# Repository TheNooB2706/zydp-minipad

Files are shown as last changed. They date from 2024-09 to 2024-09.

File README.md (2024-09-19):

# ZYDP miniPad - Hardware
This branch contains all the hardware designs (3D models, drawing and electrical schematic diagram) and images taken during the construction of the project. Unlike the software part, the organisation and documentation is much more messy.

## Files in the branch
1. `cad_model` folder contains all the 3D models in FreeCAD format and technical drawing in pdf of the project
1. `schematic` folder contains the electrical schematic in pdf and KiCAD files for the schematic and simulation
1. `images` folder contains images taken during the course of the project
1. `operation_guide` is a user manual for this project
1. `project_diaries` is a log of information throughout the project
1. `resources` is originally intended to be a place to keep all the links to the useful resources, but ended up being a log for setting up the bootloader

## Bill of materials

| **Item** | **Unit price** | **Qty** | **Cost** |
|---|---|---|---|
| **Electronics** | | | |
| Bluepill STM32F103C8T6 | 7.4 | 1 | 7.4 |
| Multiplexer 74HC4067 | 2.25 | 1 | 2.25 |
| 3.5mm Jack | 0.365 | 4 | 1.46 |
| Buttons | 0.0418 | 7 | 0.2926 |
| RGB LED common cathode | 0.13 | 1 | 0.13 |
| Ethernet cable for single core wire | 1.5 | 0.5 | 0.75 |
| NPN transistors 2SC1815 | 0.0496 | 2 | 0.0992 |
| Resistors (estimate price) | 0.016 | 21 | 0.336 |
| Prototyping board | 0.502 | 1 | 0.502 |
| Piezo elements | 0.3055 | 13 | 3.9715 |
| |
| **Mechanical** | | | |
| Sponge | 2.3 | 0.25 | 0.575 |
| EVA foam | 1.3 | 1 | 1.3 |
| Spray paint | 6.5 | 0.5 | 3.25 |
| Spray lacquer | 6.5 | 0.5 | 3.25 |
| Rubber feet | 0.104 | 6 | 0.624 |
| Mounting board | 3.5 | 1 | 3.5 |
| | | | |
| | |Total (RM)| 29.6903  |

## Image gallery

### Finished project
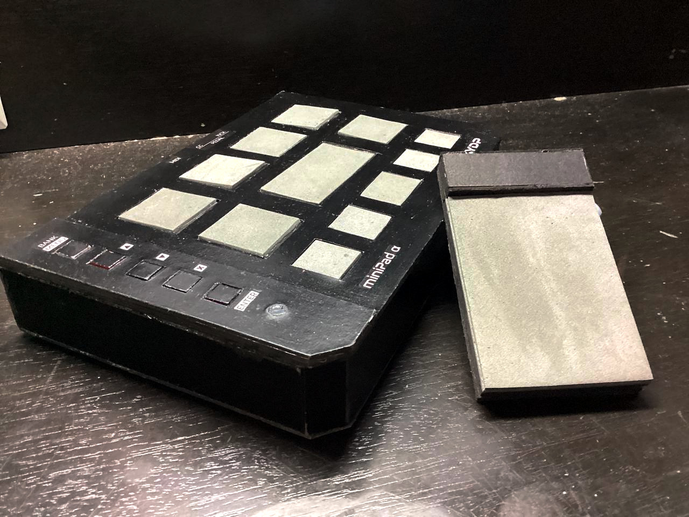
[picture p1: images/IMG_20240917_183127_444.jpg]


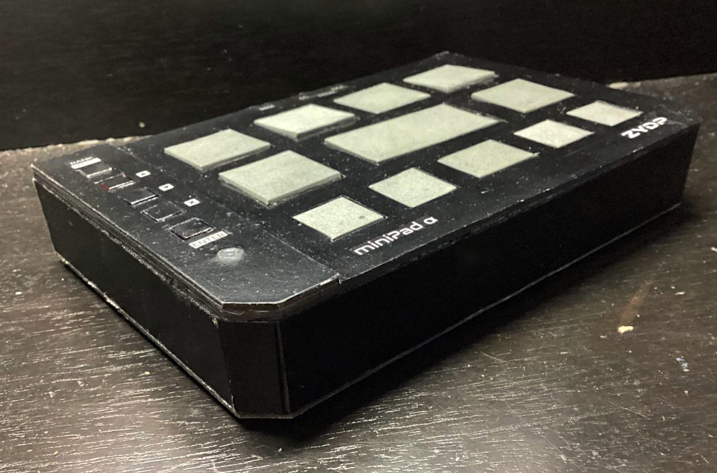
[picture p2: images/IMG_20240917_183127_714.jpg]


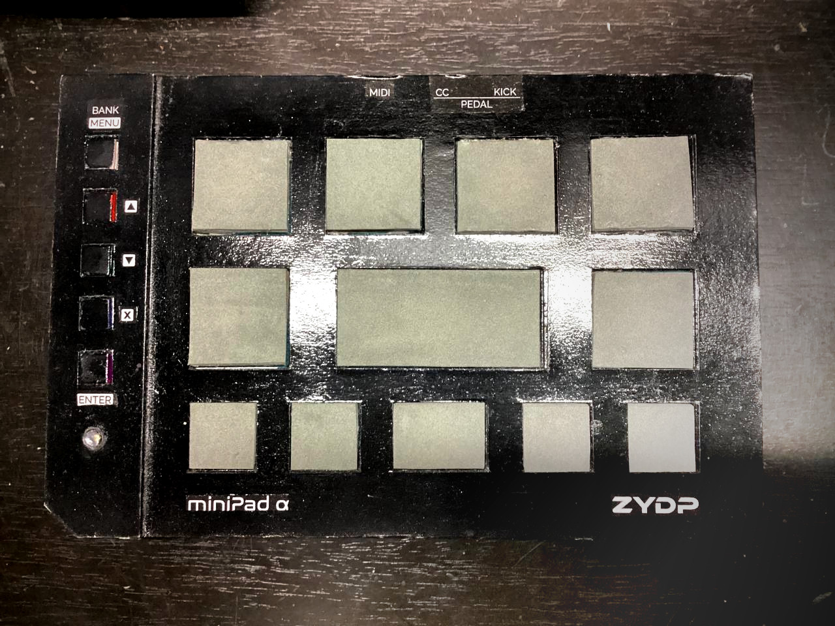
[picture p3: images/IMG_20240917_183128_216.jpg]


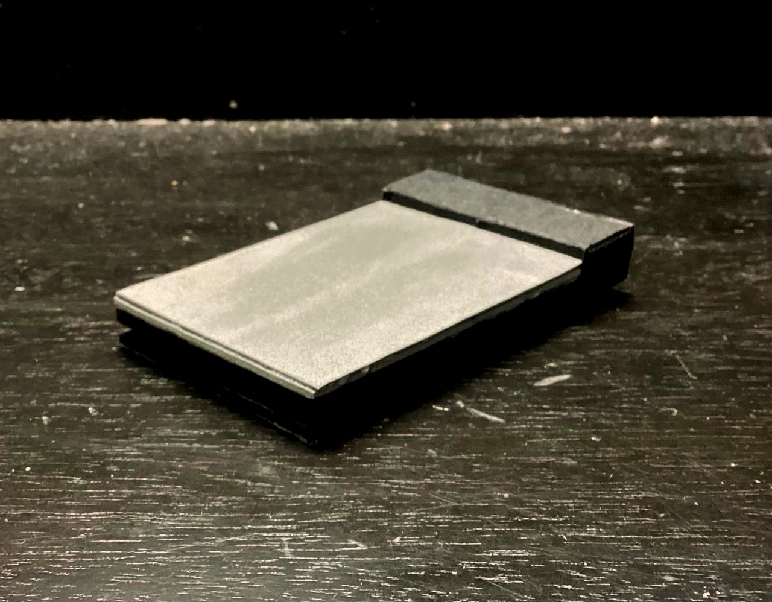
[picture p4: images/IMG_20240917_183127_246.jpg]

*Pedal unit design not included (yet)*

### During the making of the project

#### The pads

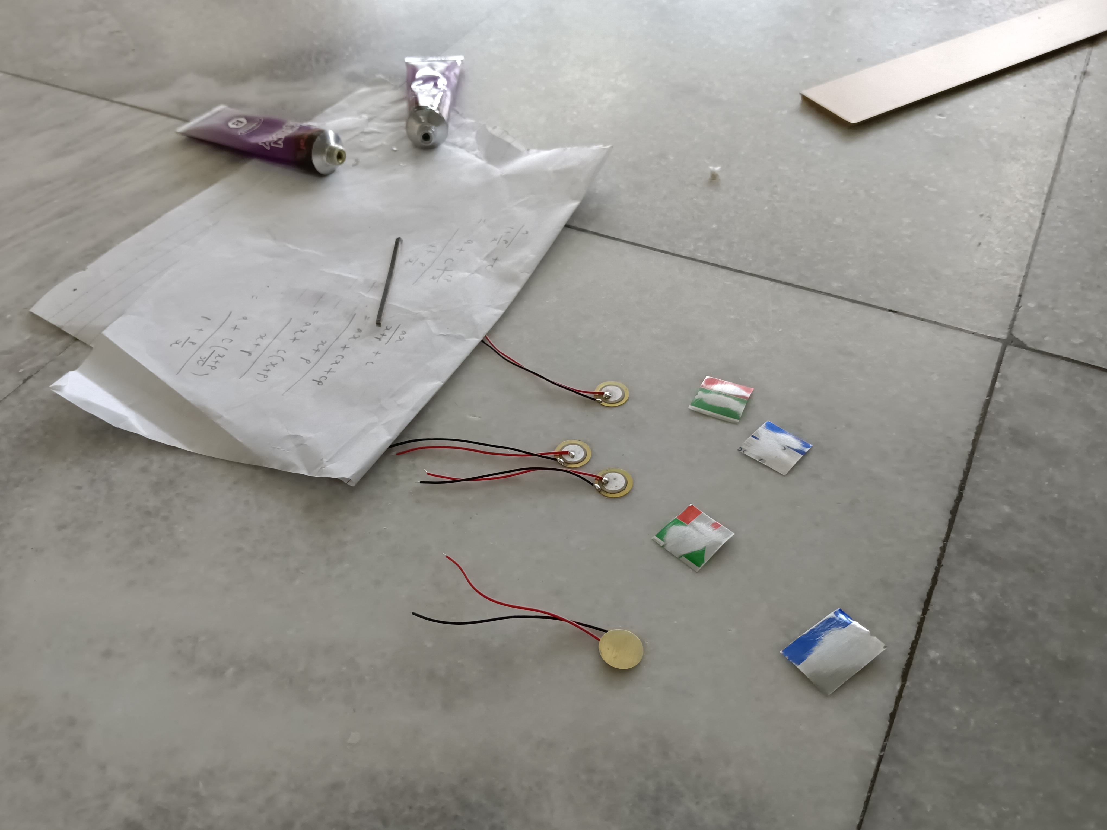
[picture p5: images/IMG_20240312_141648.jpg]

*Surface preparation of the discs and aluminum sheet cut from drinks can*

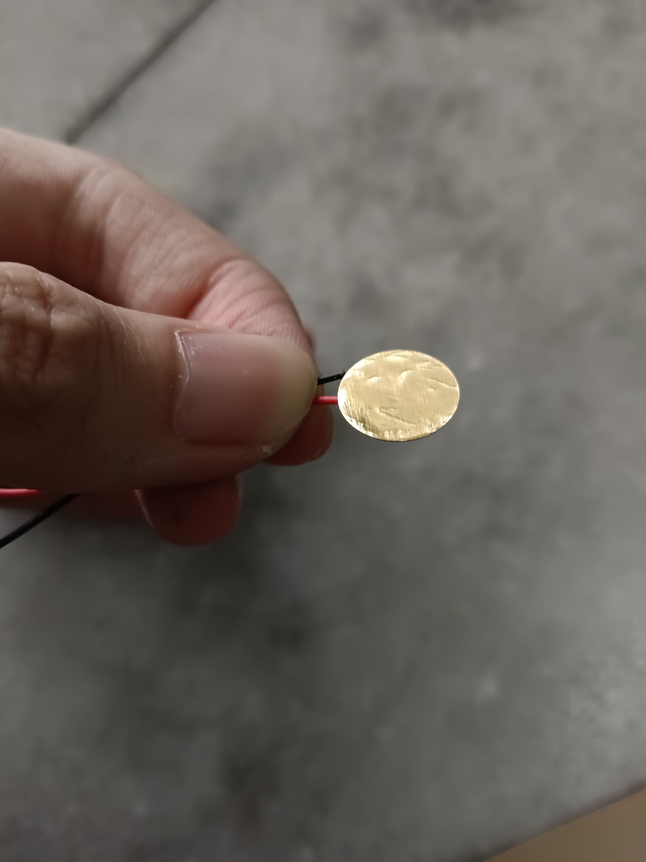
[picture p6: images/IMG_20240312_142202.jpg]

*Applied epoxy glue at the back*

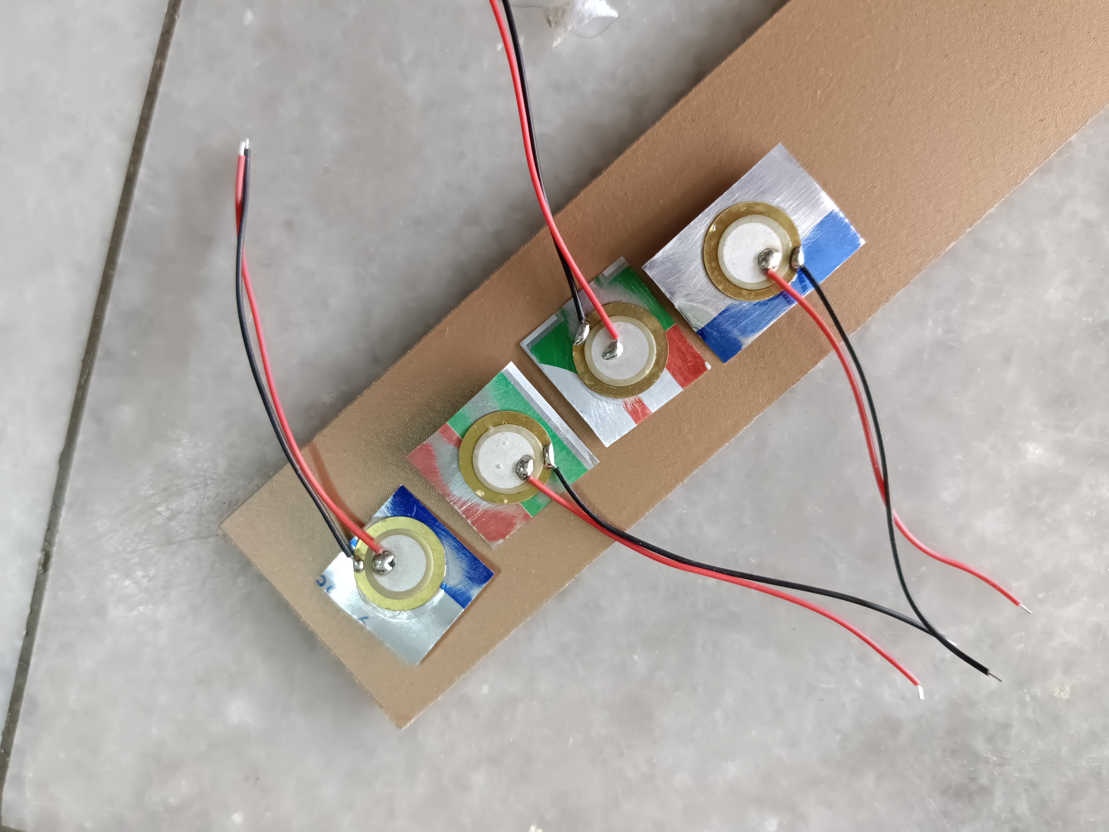
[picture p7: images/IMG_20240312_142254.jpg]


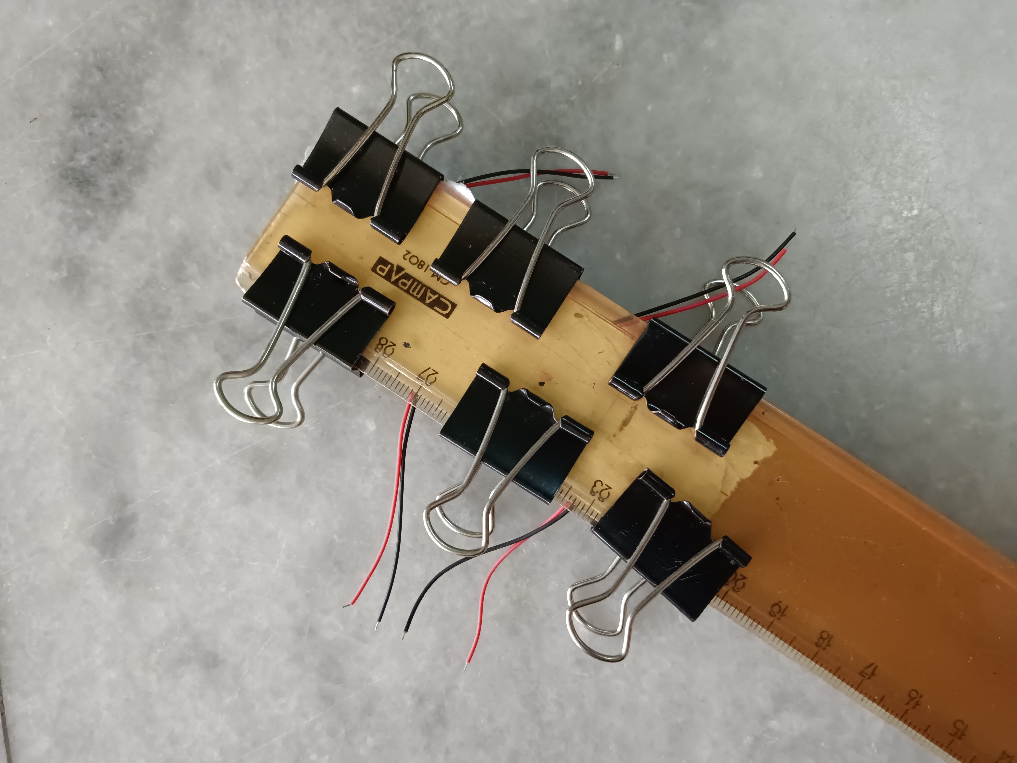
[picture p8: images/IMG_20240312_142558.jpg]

*Glued and clamped*

The layering of the disc and the aluminum sheet is to increase the area that the pad is sensitive to. Without it, it is required to hit dead center to register anything. While this does improve the problem significantly, I still do not consider it to be good enough and yet to be improved.

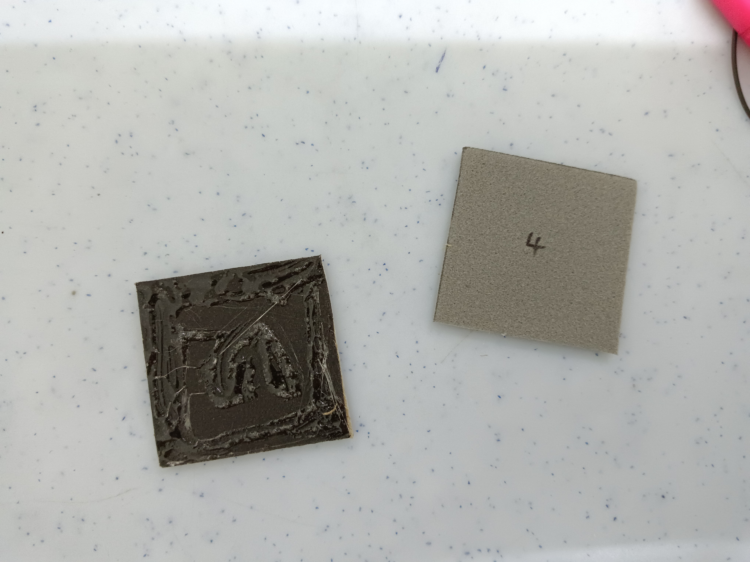
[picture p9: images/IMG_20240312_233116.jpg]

*EVA foam and mounting board cut to size*

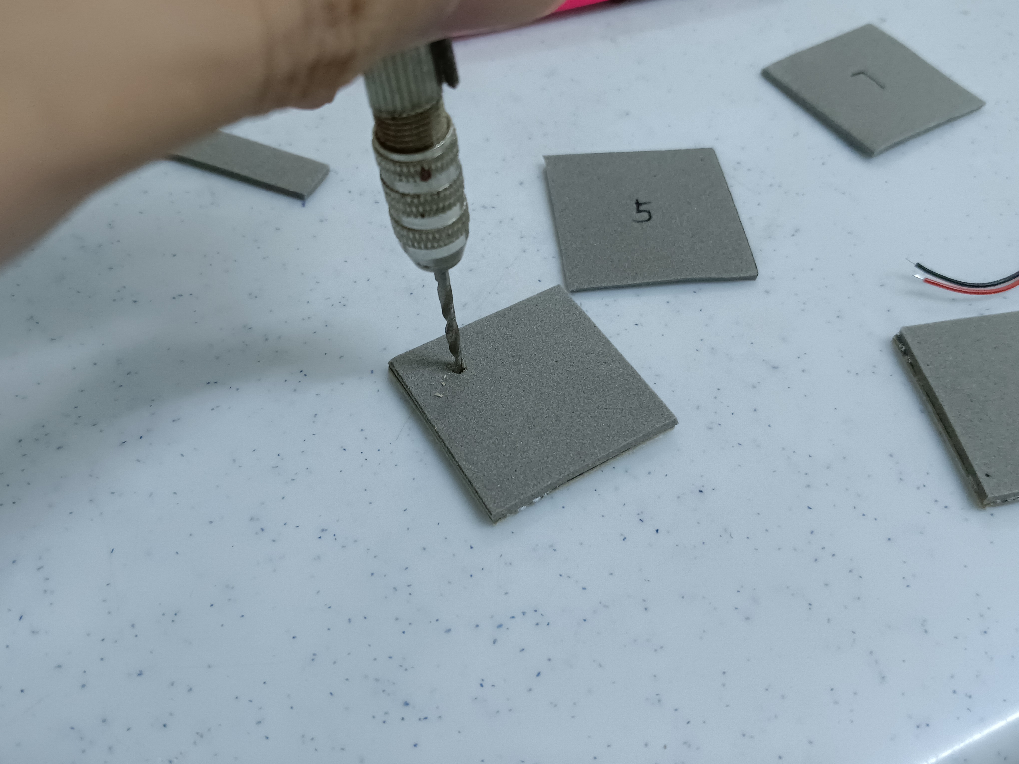
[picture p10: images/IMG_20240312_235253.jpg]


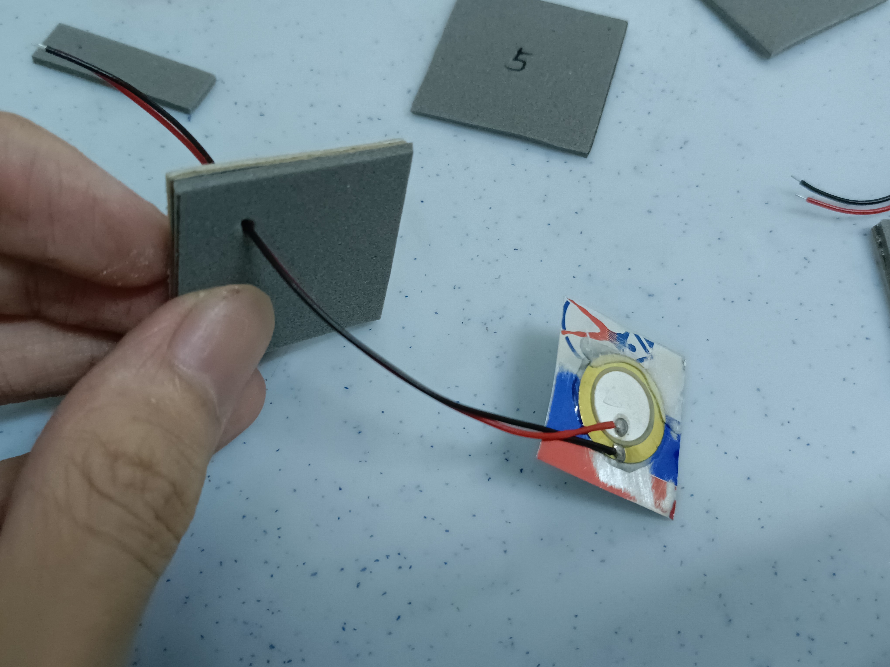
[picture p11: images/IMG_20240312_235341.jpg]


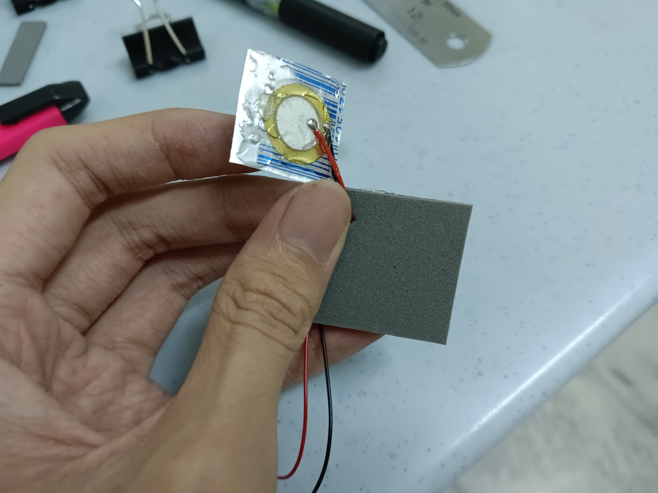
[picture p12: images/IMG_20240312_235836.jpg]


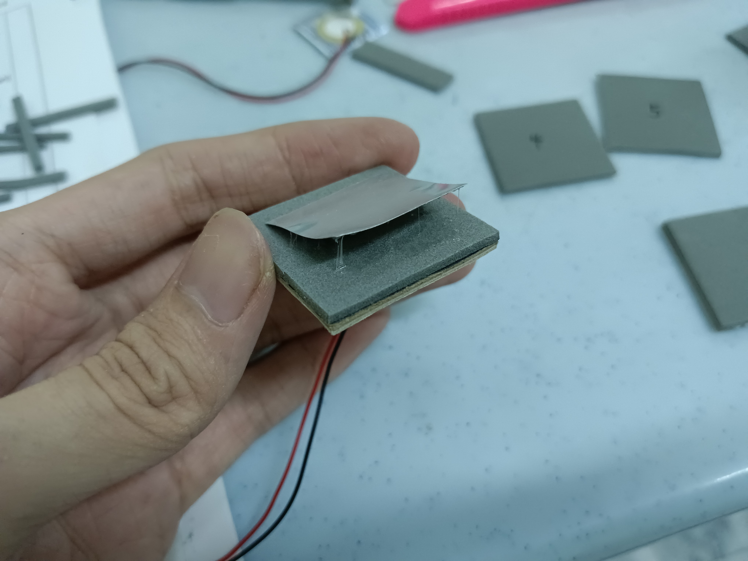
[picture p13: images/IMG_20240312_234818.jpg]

*The "aluminum-disc composite" glued on the EVA foam. This is followed by another layer of EVA foam glued on top (not shown in image)*

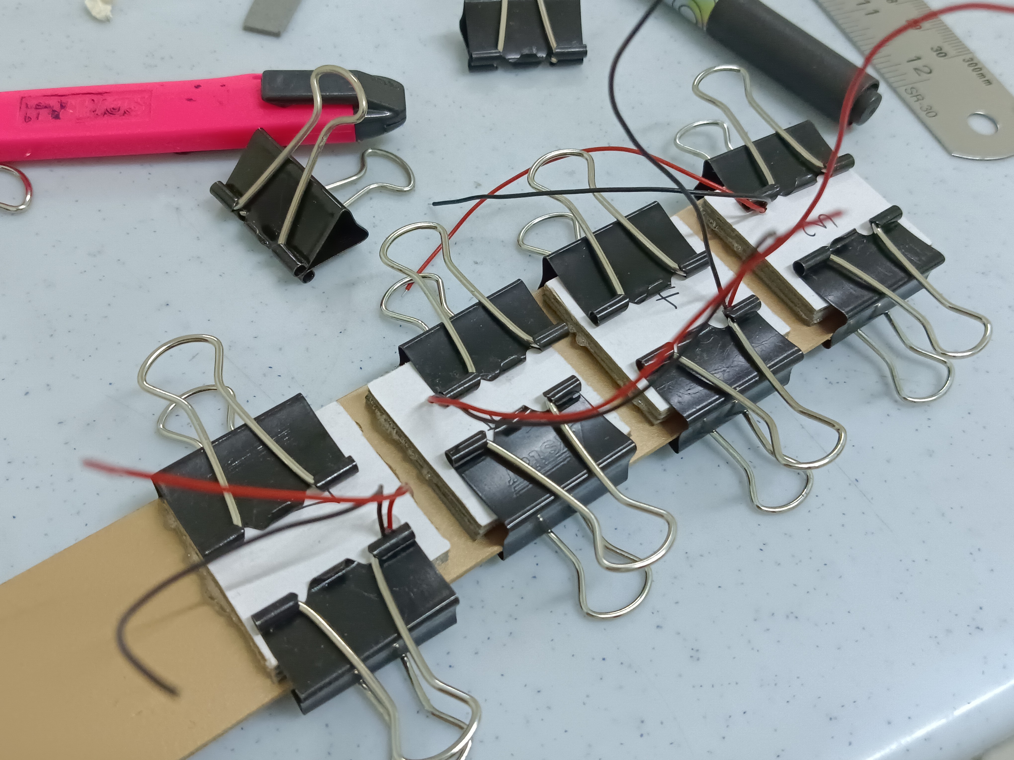
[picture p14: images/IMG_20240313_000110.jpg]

*Clamping while the glue cure*

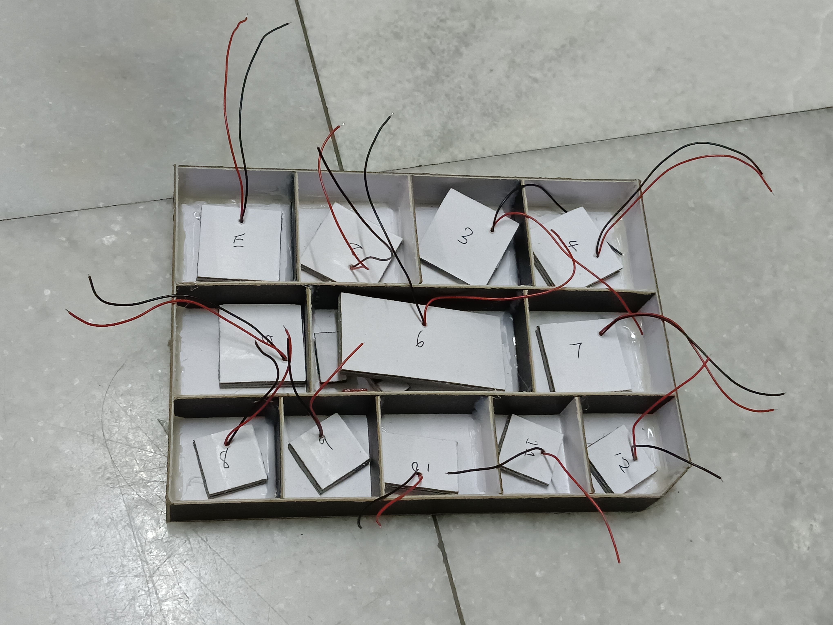
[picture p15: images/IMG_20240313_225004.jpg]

*Finished pads*

#### The pads holder
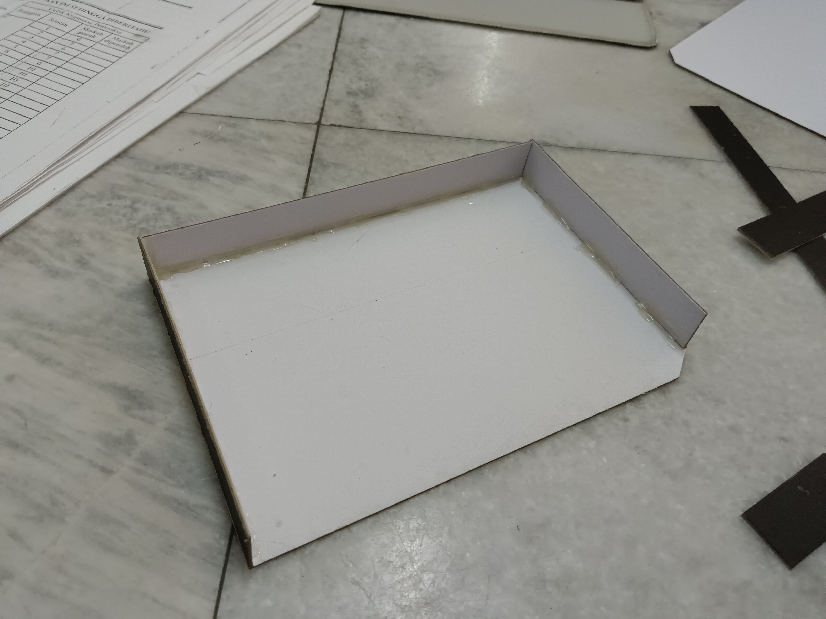
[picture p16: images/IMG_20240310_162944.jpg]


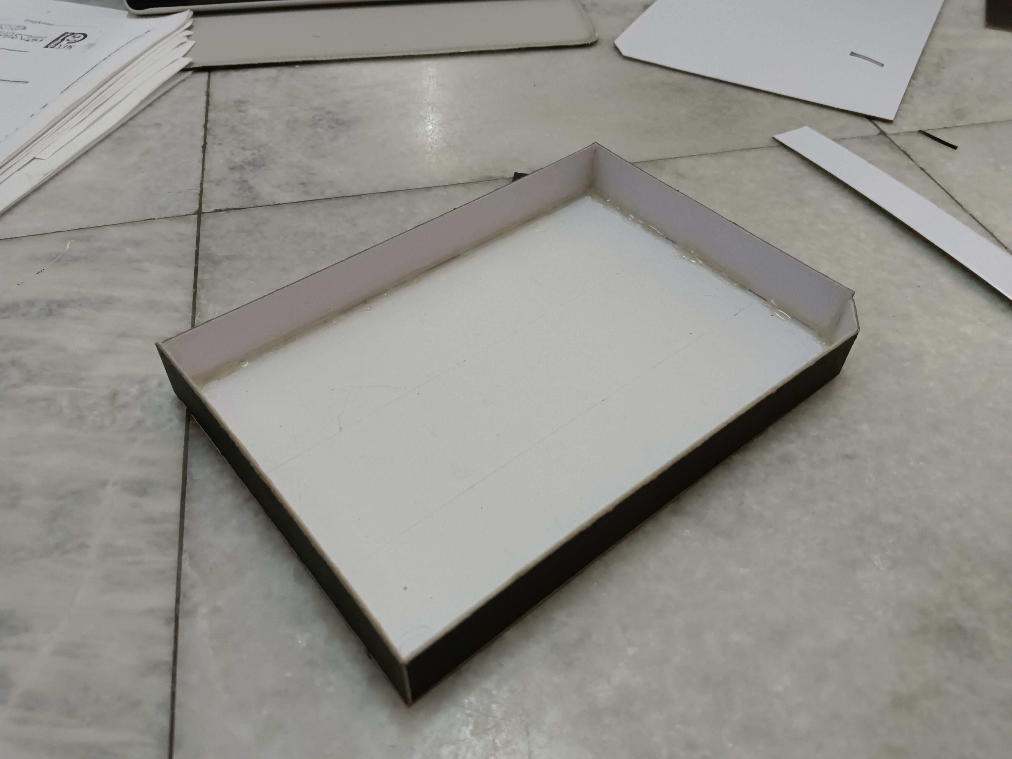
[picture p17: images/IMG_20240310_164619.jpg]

*The bottom part of the pad holder*

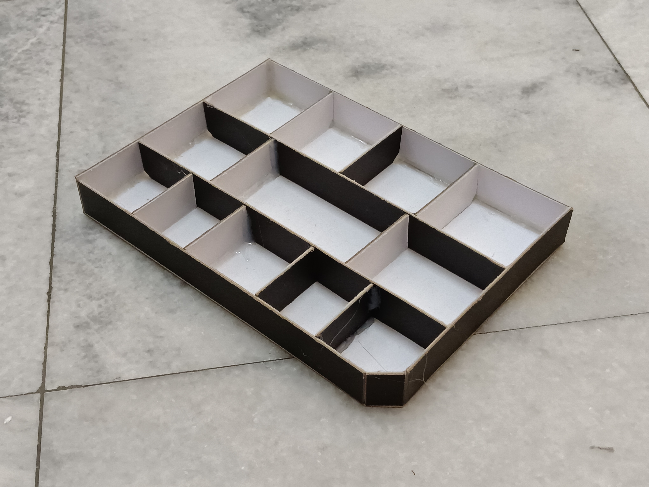
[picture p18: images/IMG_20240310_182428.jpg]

*Now with separation between pads*

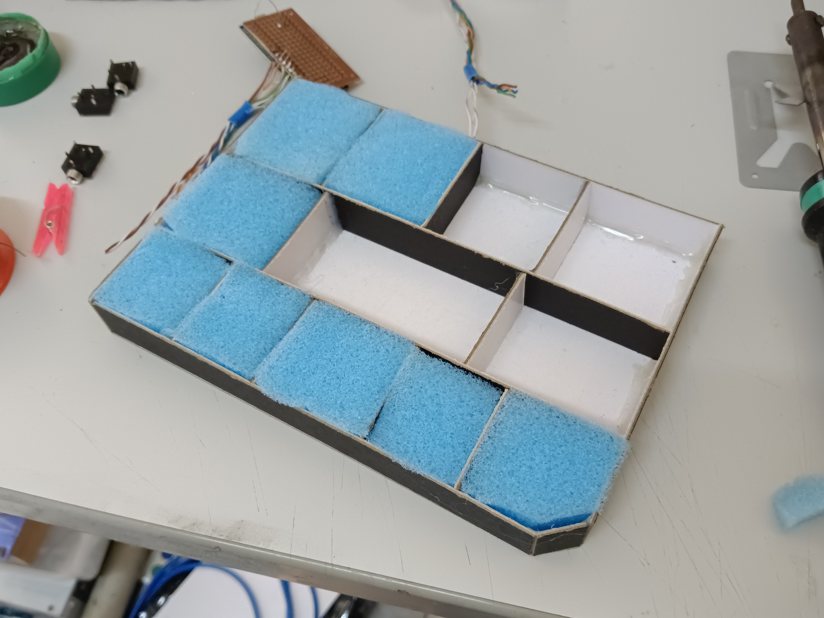
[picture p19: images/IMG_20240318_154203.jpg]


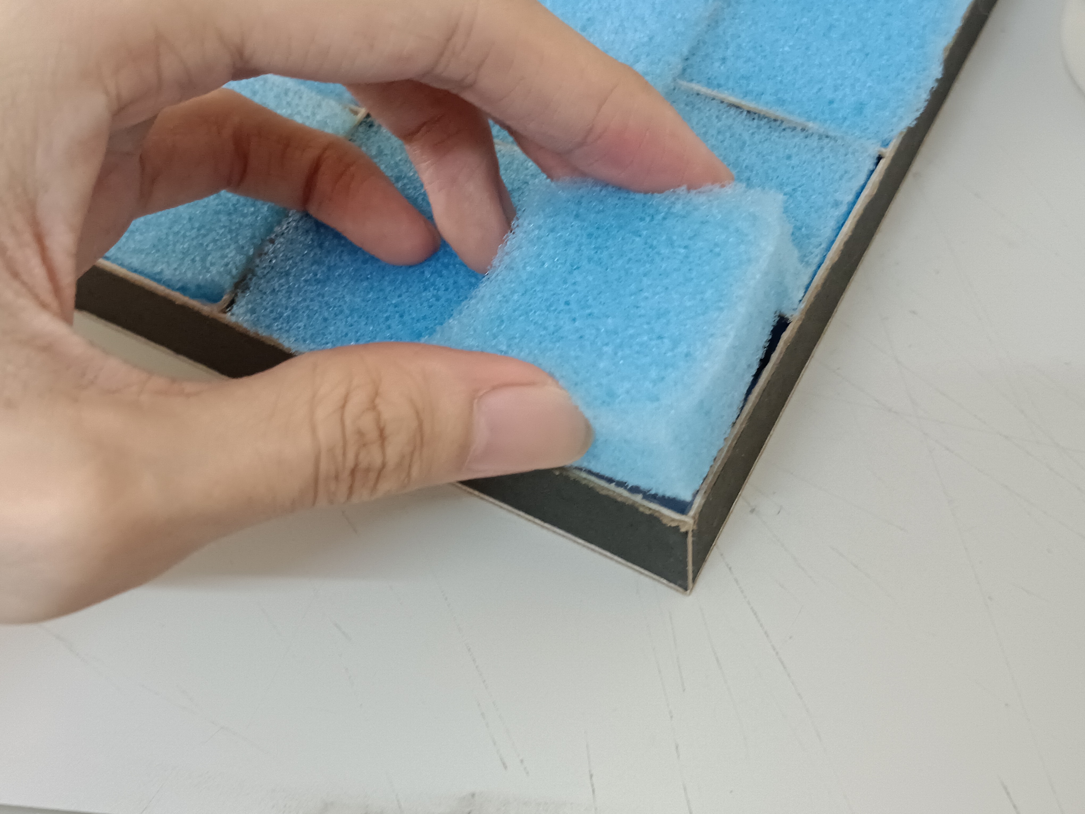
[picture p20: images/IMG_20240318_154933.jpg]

*Filling with sponge*

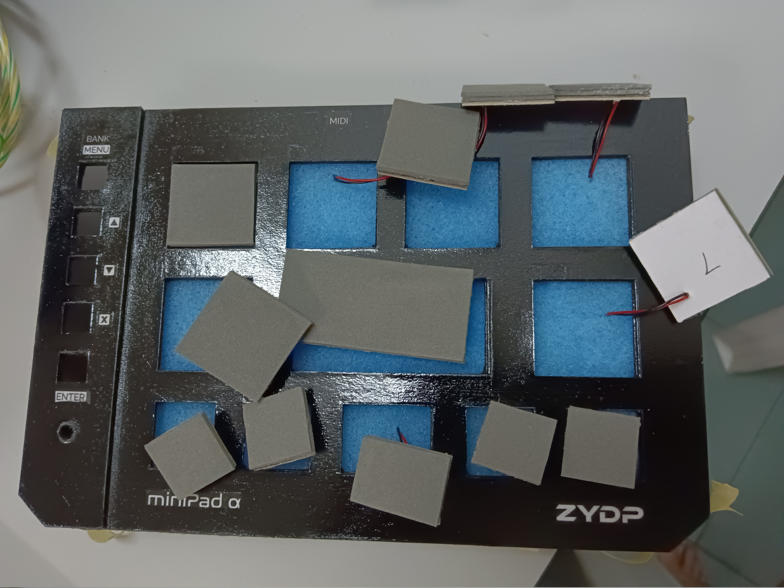
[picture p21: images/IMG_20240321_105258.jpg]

*Aligning the pads*

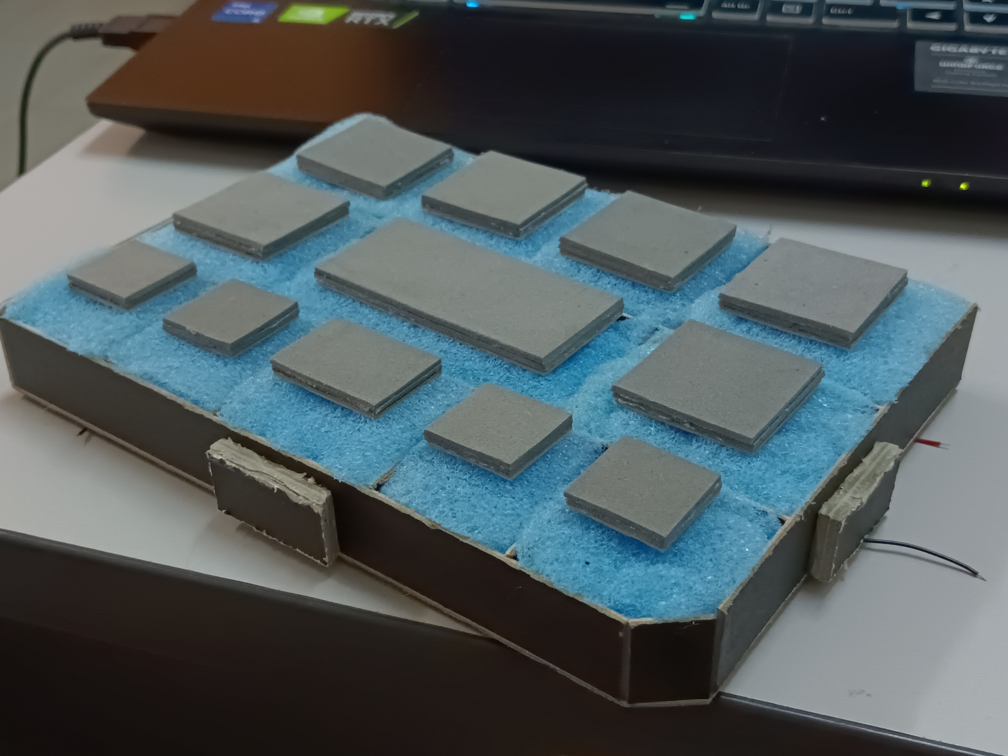
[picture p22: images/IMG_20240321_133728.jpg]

*Pads glued on top with wires passing through the bottom*

#### Buttons

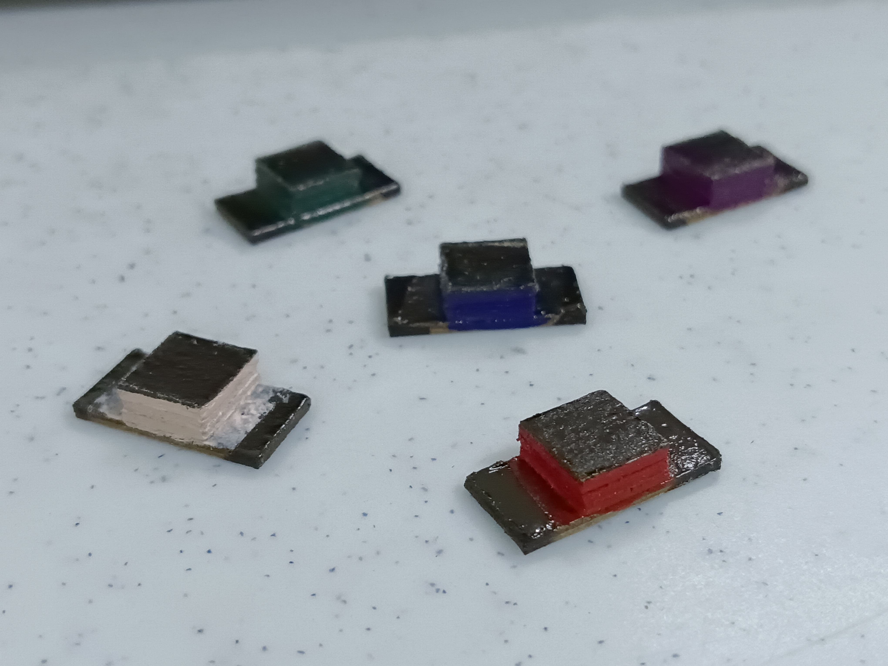
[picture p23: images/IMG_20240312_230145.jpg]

*The 5 coloured buttons. The side is coloured using poster colour and the top is spray painted black. Then lacquer spray is applied over entire thing*

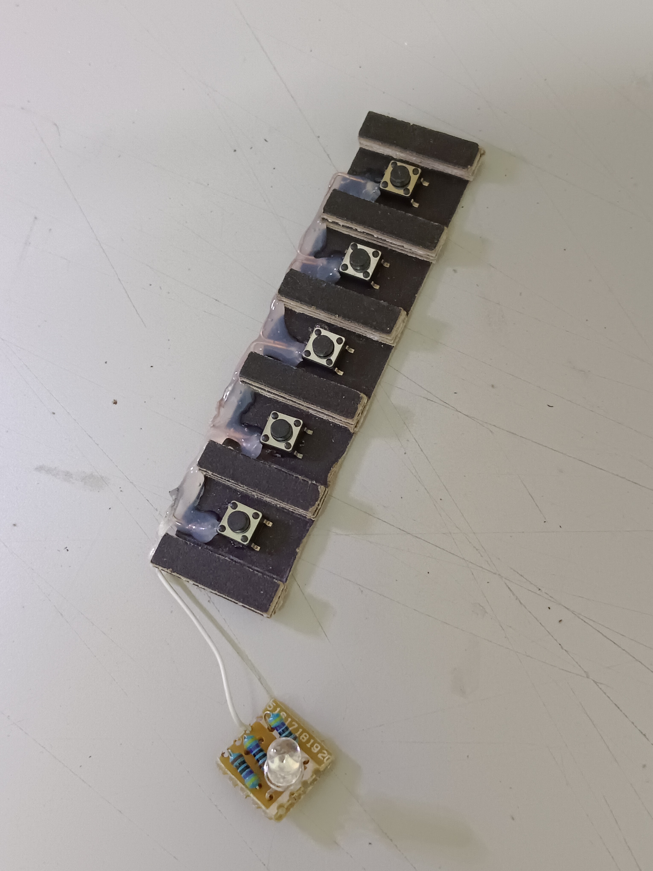
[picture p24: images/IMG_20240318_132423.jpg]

*The platform that will hold the push buttons. The LED is wired together.*

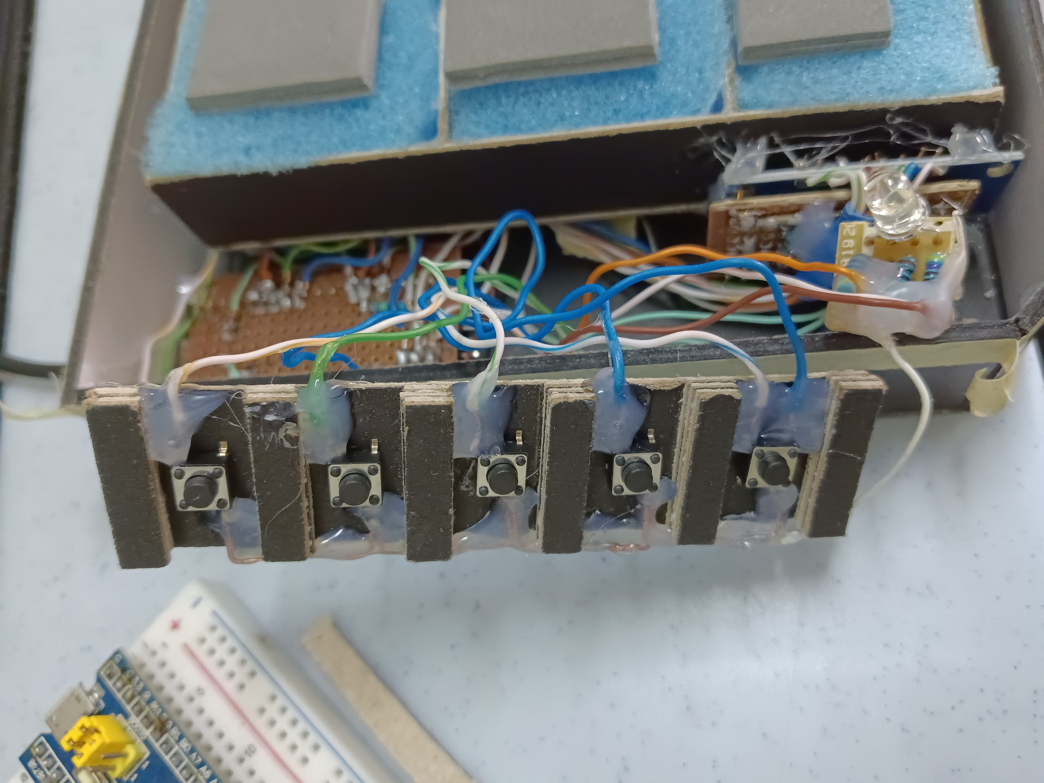
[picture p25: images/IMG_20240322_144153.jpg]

*Buttons ready to be glued*

#### Faceplate

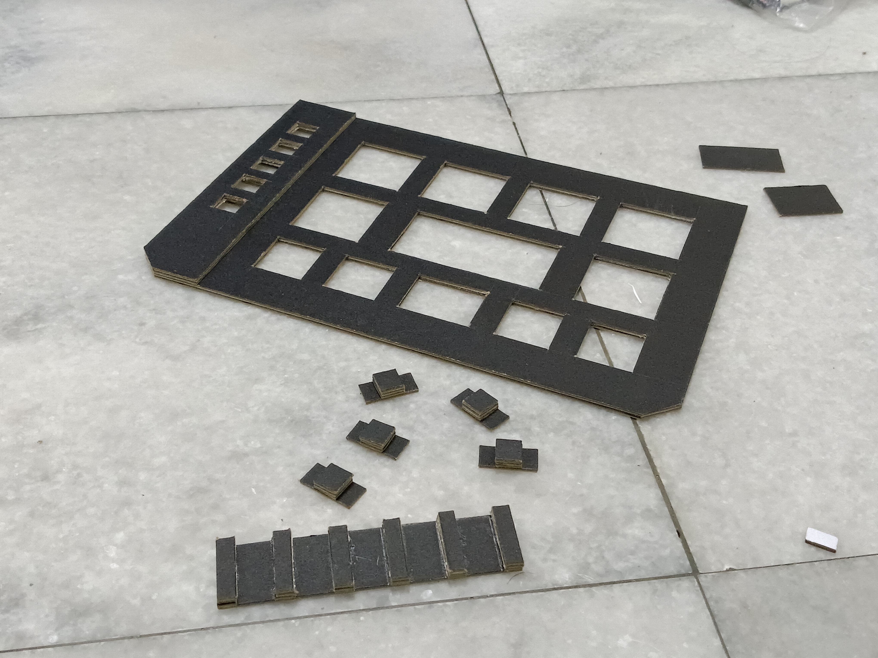
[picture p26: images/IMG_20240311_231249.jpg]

*Freshly cut faceplate, those holes took forever to hand cut, I need a laser cutter. Other freshly cut parts are also shown in the images*

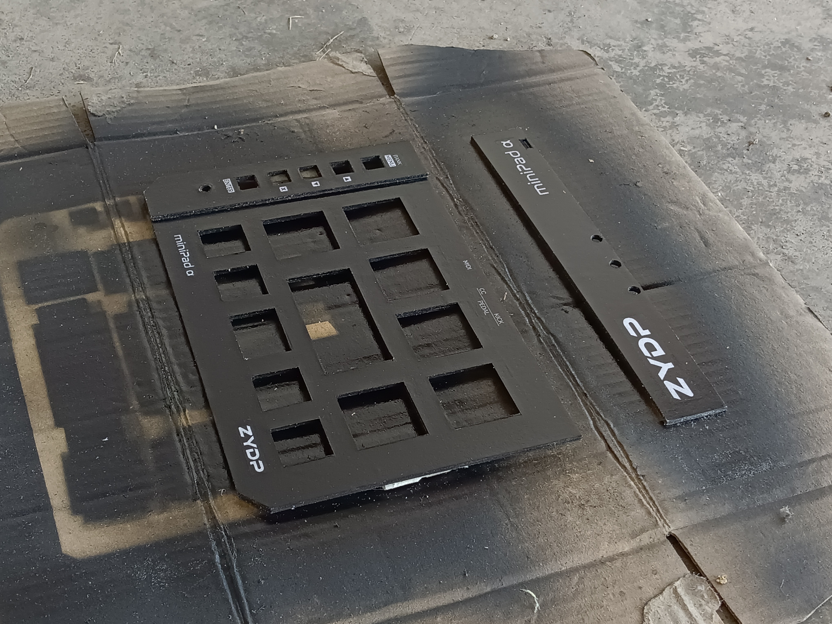
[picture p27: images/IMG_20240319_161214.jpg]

*Printed label is glued on top and sprayed painted over. The procedure is described in the `project_diaries` file*

#### Enclosure body

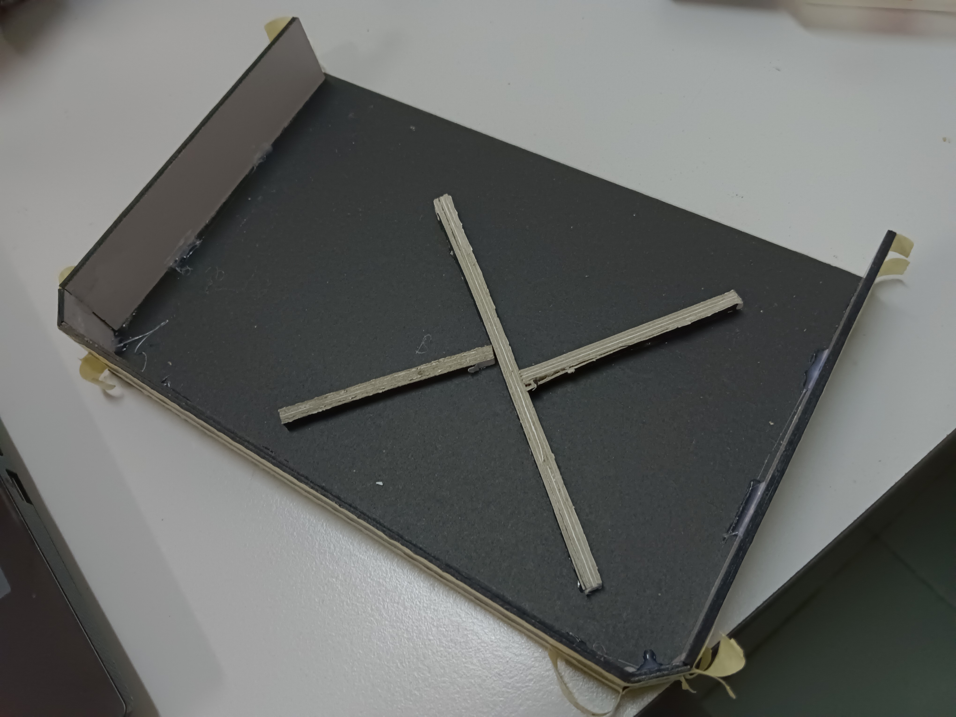
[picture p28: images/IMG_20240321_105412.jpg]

*Constructing the enclosure. Of course the "X" support cause the entire thing to be warped because it is not flat*

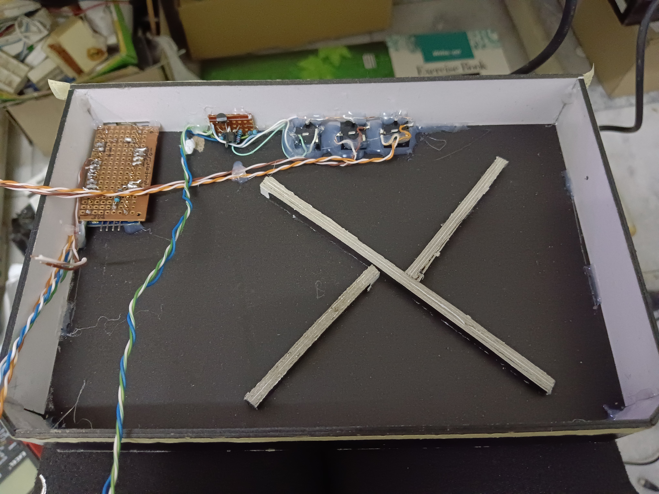
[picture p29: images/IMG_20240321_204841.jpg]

*Back panel mounted and the development board, TRS MIDI circuit and 3.5mm jack ~~installed~~ glued*

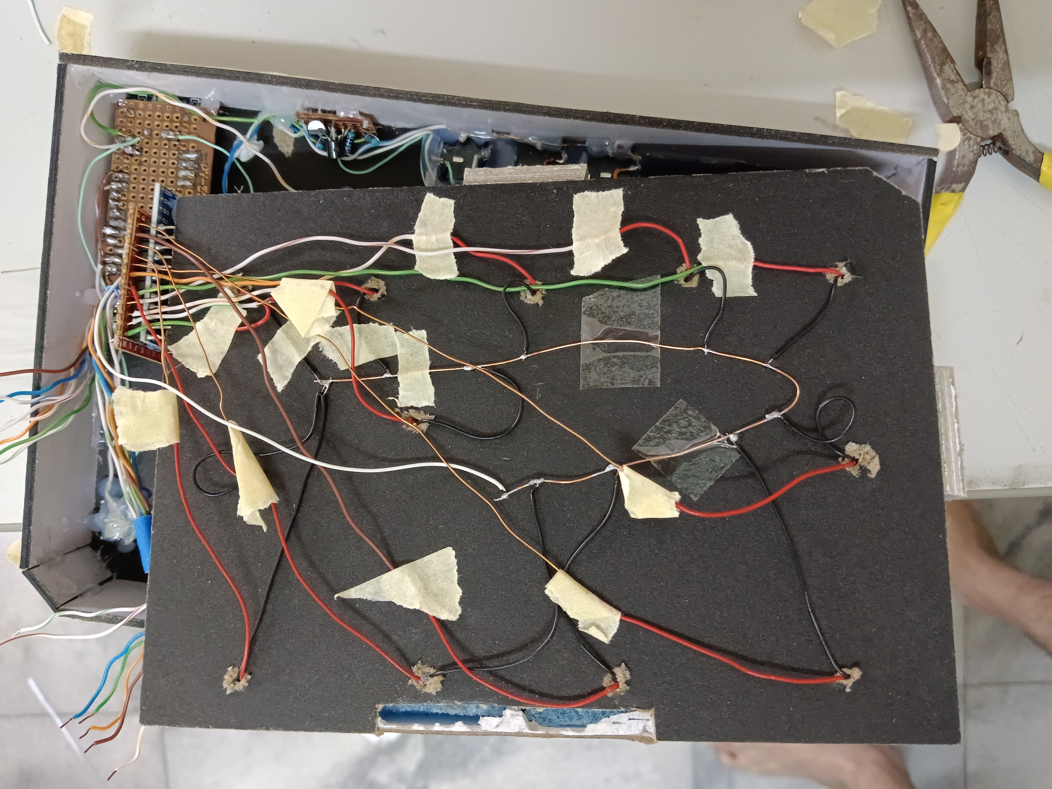
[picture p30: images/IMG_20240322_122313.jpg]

*Ahh I'm not proud of this wiring*

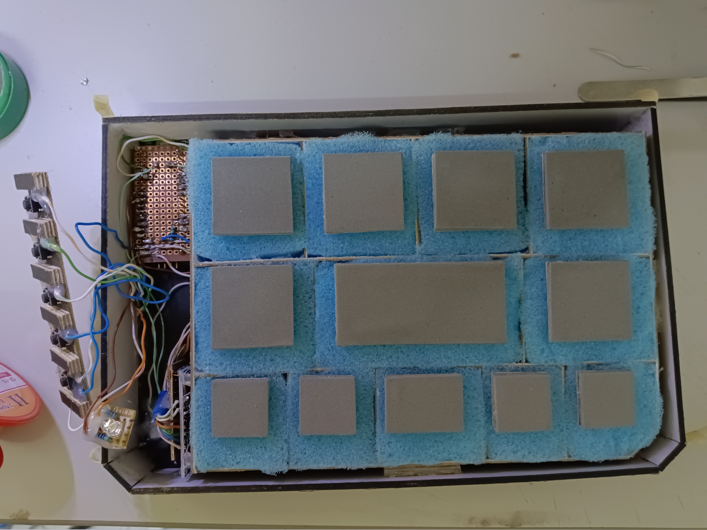
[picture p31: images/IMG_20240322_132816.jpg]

*Pad holder successfully installed*

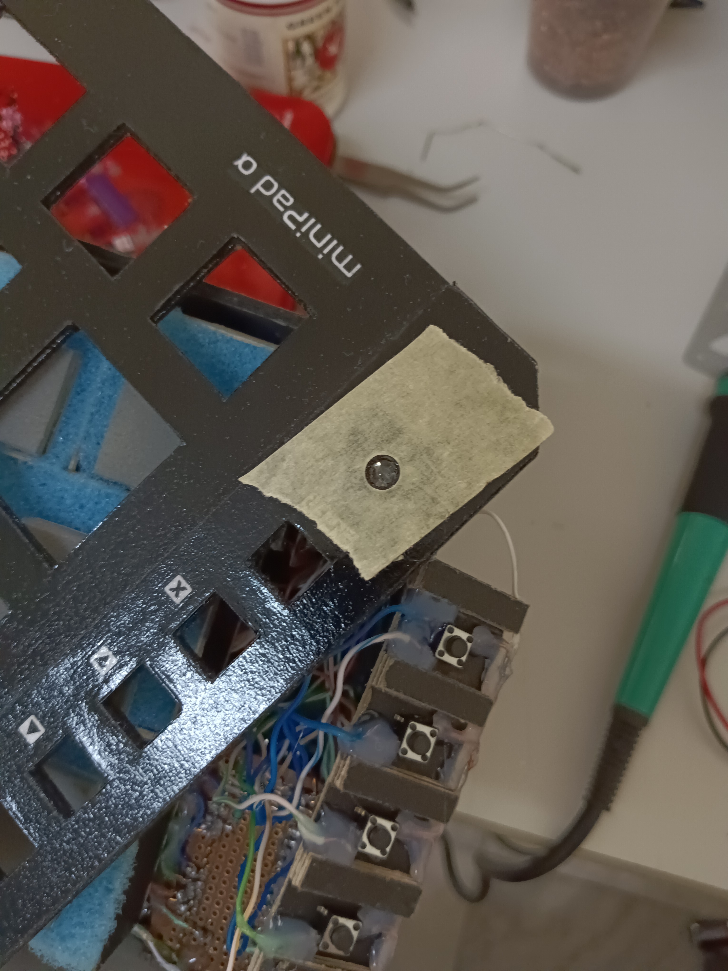
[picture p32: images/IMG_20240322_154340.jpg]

*Mounting the LED with epoxy but failed, so hot glue it is*

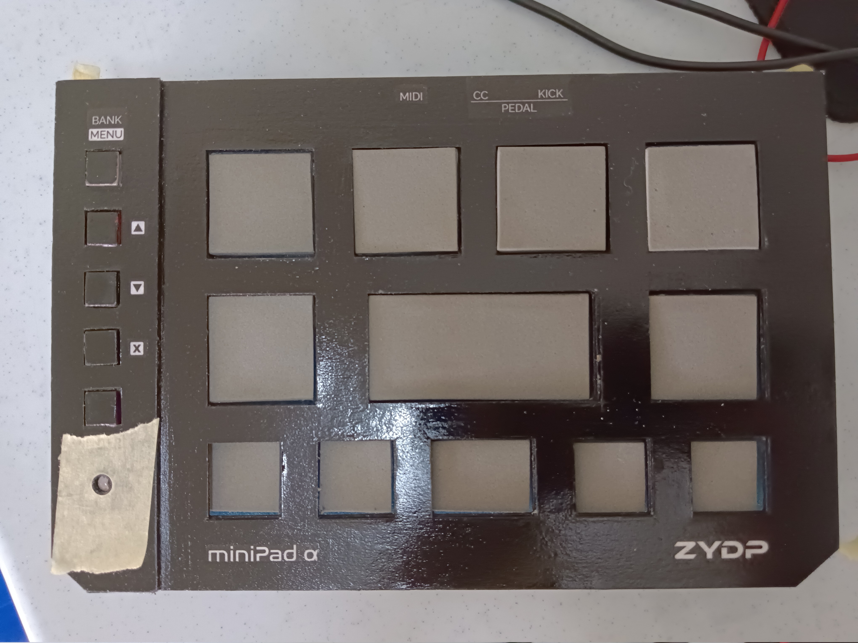
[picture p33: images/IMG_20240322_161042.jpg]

*Installing the faceplate*

## License

The hardware and all the designs in this branch are licensed under [CERN Open Hardware Licence Version 2 - Weakly Reciprocal](LICENSE).

The images are licensed under [Creative Commons Attribution 4.0 International](CC-LICENSE).

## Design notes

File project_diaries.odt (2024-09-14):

## 22/2/2024: Got the LED blinking, and documented some stuff that should be documented before

### Software

- Choosing bootloader: STM32duino-bootloader by rogerclarkmelbourne
- Method to flash bootloader: stm32flash tool on Linux. Windows? Good luck.
- Working platformio configuration:
  - platform = ststm32
  - framework = arduino
  - board = genericSTM32F103C8
  - board_build.core = maple
  - upload_protocol = dfu
  - build_flags = -D PIO_FRAMEWORK_ARDUINO_ENABLE_CDC -Os
- Simple test with the USBComposite library.
- Things to not do: Initialize USBComposite library without USBCompositeSerial. No longer detected for second programming. If this happens, do flash again by using dfu-util directly.
- When initializing the USBComposite:
  - Do not call plugin.begin, things will break. Once USBComposite.begin is called, things are good to go.

## 28/2/2024: Surface finish test 1 – Logo and text

### Procedure:

1. The text is printed out on 80gsm paper with inverted color (black outside, so text is white). But since it is not wise to print the entire panel with black ink (bye bye printer ink), only the region close to the text is printed.
2. The region around the text is masked off, and black paint is sprayed to the surface. 2 coating is done, 5 minutes between coating.
3. The masking is removed, lacquer spray is applied to the entire surface. 2 coating is done.

### Result:

- The area with black spray paint and the region around the text is clearly discernable.
- Warping occur.
- The lacquer coating soaked into the paper around the text area, causing it to not be gloss.
- The spray paint area however, looks very nice

### Impromptu post-procedure and observation:

- A third coating of lacquer is sprayed.
  - The lacquer start to not soak into the paper, and the text area starts to look glossy.
- The spray paint area is masked of so the lacquer can be applied on the text only.
  - The text area looks way more finished and probably already ok for the final product.
  - Unfortunately masking tape is applied too early, so the lacquer is ripped off

### Suggestion for future iteration:

- The following improved procedure can be tried:
  - Mask off text area, apply 2 layers of black spray paint, 5 minutes between coating. Wait at least an hour for it to throughly dry.
  - Remove masking tape and masked off the spray painted area. Apply 2 layers of lacquer coating to the text area, 5 minutes between coating. Wait at least an hour for it to throughly dry.
  - Remove masking tape and apply 2 layers of lacquer to the entire surface.

## 3/3/2024: Surface finish test 2

Following the suggested procedure from test 1, with a much smaller area:

### Result:

- Color between the painted area and text area is slightly discernable.
- Specularity however is even across the entire surface.
- Obvious edge around the masked boundary is observed. This might be caused by peeling off the masking tape too early, but this might not be the main reason.

### Suggestion for future iteration:

- Can try sanding the surface before applying lacquer to entire surface.
- The following improved procedure can be tried:
  - Mask off text area, apply 2 layers of black spray paint, 5 minutes between coating. Wait at least an hour for it to throughly dry.
  - Remove masking tape and masked off the spray painted area. Apply 2 layers of lacquer coating to the text area, 5 minutes between coating. Wait at least an hour for it to throughly dry.
  - Remove masking tape and sand the boundary until not discernable.
  - Apply 2 layers of lacquer to the entire surface.
- Maybe we need to go with custom decals sticker instead? ($$$)

## 6/3/2024: Pad and related software test 1

- Velociy mapping using exponential function is decent.
- Pad made with single layer of EVA foam has great discrepencies in reading when different region of the pad is hitted. Double layer of EVA foam is preferable but requires more material
- However, double layer of EVA foam appear to have less sensitivity when testing on UNO.
- The current trigger detection is usable, although might not be optimal.
- Sponge is a bit too soft and deform too easily, but is probably not a problem when made into the project since the sponge will be glued to the holder on all sides except top.

## 6/3/2024: Surface finish test 3

Following the latest improved procedure, was very close to success. However in step 2, it turn out the lacquer layer is a bit too thin due to variation in application, the final result is clearly two different layer when touched. Specularity is almost perfect.

### Impromptu test

Using the last failed result in test 2, the surface is sanded down and another layer of lacquer is applied. The result is perfect and ready for production.

### Suggestion for future iteration:

- Mask off text area, apply 2 layers of black spray paint, 5 minutes between coating. Wait at least an hour for it to throughly dry.
- Remove masking tape and masked off the spray painted area. Apply 2 layers of lacquer coating to the text area, 5 minutes between coating. If the surface does not appear shiny, continue to add lacquer layer. Finally, wait at least an hour for it to throughly dry.
- Remove masking tape and sand the boundary until not discernable.
- Apply 2 layers of lacquer to the entire surface.

## 8/3/2024: Surface finish test 4

The first test had the lacquer at the text area ended up being too thick. 3 layers of coating is applied in total and this is too much and cannot be sanded away. Additionally, the lacquer soak into the paper causing significant degrade in the contrast of the text. The second test had first two coating, 4 pass each applied followed by the third 8 pass coating of lacquer, the resulting thickness is good, but soaking occur when the third layer is applied.

### Suggestion for future iteration:

- Mask off text area, apply 2 layers of black spray paint, 5 minutes between coating. Wait at least an hour for it to throughly dry.
- Remove masking tape and masked off the spray painted area. Apply 4 layers of lacquer coating to the text area, 4 passes each, 5 minutes between coating. Wait at least an hour for it to throughly dry.
- Remove masking tape and sand the boundary until not discernable.
- Apply one layer of lacquer to the entire surface. Wait one hour for drying.
- Sand the surface again and apply final layer of lacquer.

## 9/3/2024: Surface finish test 5

The following procedure is used:

1. Mask off text area, apply 2 layers of black spray paint, 5 minutes between coating. Wait at least an hour for it to throughly dry.
2. Remove masking tape and masked off the spray painted area. Apply 4 layers of lacquer coating to the text area, 4 passes each, 5 minutes between coating. Wait 15 minutes for it to throughly dry.
3. Remove masking tape and sand the boundary until not discernable.
4. Apply one layer of lacquer to the entire surface. Wait one hour for drying.
5. Sand the surface again and apply final layer of lacquer.

So far this had the best result. The specularity and also thickness are not discernable, only the background color is slightly different. Problem with lacquer soaking into the paper is also completely eliminated. This procedure will be used for the final project.

### Suggestion for future iteration:

To eliminate the slight color difference, a few things can be tried:

1. For black color, use laser printer instead of inkjet printer because the ink is probably darker?
2. For other color, color match the printed color and the spray paint color before designing the actual panel. A procedure for color matching is proposed as below:
  i. Print a strip of linear color gradient. Apply the surface finish procedure.
  ii. Measure the length from one end to the point where the color appear to be the same.
  iii. Correspond that to the point in the digital copy and use color picker to get the exact color value.

## ??????: Completely forgot to do documentation

## 23/3/2024: Hardware fully finished according to schematic

Using the crude software for testing, a few things that need to be improved are as follow:

1. Pad crosstalk. It is unclear whether this is caused by electrical or mechanical coupling between the pads. Doing multiple analogRead seems to have negligible effect, adding a delay after setting the multiplexer address significantly improved the situation, although the problem still remain annoying
2. Unreasonable precision expected from hand cutting. Some of the pads are barely able to fit through the holes. Future iteration should match each pads individually, more work but unfortunately the only solution for hand made project
3. The largest rectangular pad have extremely bad response variability with respect to position of the pads hitted. Others do have some significant variation but not as annoying. It is to be noted that maybe piezo sensors is not the most suitable choice for finger drumpad. Force sensitive resistor might be better choice and is seen in commercial product.
4. Clearance for the output jack in the design is not enough, leading to problem during assembly where the pad holder barely fit. While the top panel is succesfully glued together, significant warping can be observed due to this problem. Additionally, some of the pads are protruding out of the panel leading to unprofessional look. Hot glue is used to fix the protruding pads to remain below the surface, but such solution reduced the sensitivity of the pad.
5. Pad holder design is, bad. First of all, proper test had not been done verify the necessity of such “sponge holder”. This design is inspired by actual drumpad (hit by drumsticks instead of finger) project (https://www.youtube.com/watch?v=ZOAaDEYHt2U&t=1714s&pp=ygULZGl5IGRydW1wYWQ%3D) by OMANK KACAU on YouTube. In future iteration, proper test should be done for this aspect.
  i. The production of the pad holder is tedious, requiring many individual parts to be produced and assembled with hot glue
  ii. The individual pockets required sponge to be cut and fitted into the space, which caused inconsistency in the stiffness of the pads when pressed.
  iii. The purpose of the pad holder had not been fulfilled, crosstalk still occur.
  iv. Maybe just a piece of sponge is enough for the purpose?

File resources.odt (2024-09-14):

## Flashing bootloader

No money to buy stlink? Flash using UART

First, grab bootloader from: https://github.com/rogerclarkmelbourne/STM32duino-bootloader/

- Flashing bootloader using stm32flash program (need to compile, linux, method used)
  - simple guide: https://pa1tech.github.io/anveshak/self/bootloadSTM32.html
    - RX-A9, TX-A10, VCC-5V, GND-G
  - stm32flash from: https://sourceforge.net/projects/stm32flash/
  - upload success:

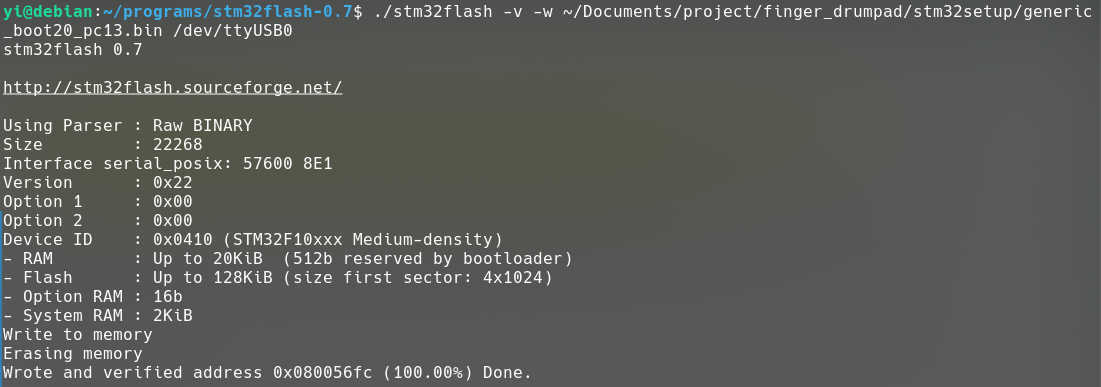
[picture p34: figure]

- Flashing bootloader using stm32loader python script (did not get it work, python version 2)
  - https://www.marrold.co.uk/2017/08/flashing-bootloader-on-to-stm32-blue.html
- Windows guide
  - https://circuitdigest.com/microcontroller-projects/programming-stm32f103c8-board-using-usb-port
  - Involve downloading sketchy exe file. Didnt get it work because windows need driver for ftdi, and can’t get the driver working

## Trying to program the thing

Platformio ini file:

[env:genericSTM32F103C8]

platform = ststm32

framework = arduino

board = genericSTM32F103C8

board_build.core = maple

upload_protocol = dfu

build_flags = -D PIO_FRAMEWORK_ARDUINO_ENABLE_CDC -Os

lib_deps = arpruss/USBComposite for STM32F1@^1.0.9

Got the bootloader, just press upload right? Righ…..

### Problem 1: upload-reset

Ran into this issue last time, didn’t document, but probably the following links are helpful.

- https://github.com/platformio/platform-ststm32/issues/225
- https://community.platformio.org/t/upload-reset-no-such-file-or-directory/8656/5

### Problem 2: setDIR: TIOCMSET: Conection timed out

Press upload, bam nothing happens, press upload second time (advanced upload):

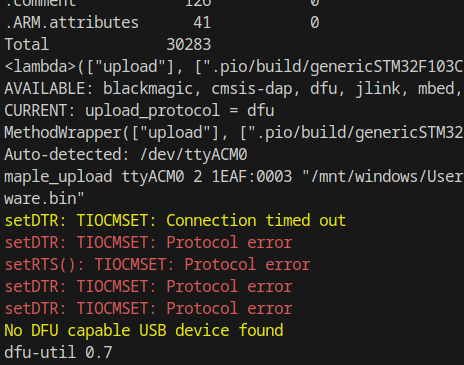
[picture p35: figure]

Wth even is this

- https://github.com/rogerclarkmelbourne/STM32duino-bootloader/issues/68

Workaround: press reset button when after reaching “Looking for upload port…”

Alternative upload with dfu-util directly:

dfu-util -a 2 -D <path to firmware.bin>

Remember we want to write to 0x8002000. Don’t ask why. Idk. List dfu device and check alt=2, hence the -a 2 argument in the command:

$ dfu-util -l

dfu-util 0.11

Copyright 2005-2009 Weston Schmidt, Harald Welte and OpenMoko Inc.
Copyright 2010-2021 Tormod Volden and Stefan Schmidt
This program is Free Software and has ABSOLUTELY NO WARRANTY
Please report bugs to http://sourceforge.net/p/dfu-util/tickets/

dfu-util: Cannot open DFU device 04f2:b729 found on devnum 3 (LIBUSB_ERROR_ACCESS)
Found DFU: [1eaf:0003] ver=0201, devnum=51, cfg=1, intf=0, path="1-1", alt=2, name="STM32duino bootloader v1.
0 Upload to Flash 0x8002000", serial="LLM 003"
Found DFU: [1eaf:0003] ver=0201, devnum=51, cfg=1, intf=0, path="1-1", alt=1, name="STM32duino bootloader v1.
0 Upload to Flash 0x8005000", serial="LLM 003"
Found DFU: [1eaf:0003] ver=0201, devnum=51, cfg=1, intf=0, path="1-1", alt=0, name="STM32duino bootloader v1.
0 ERROR. Upload to RAM not supported.", serial="LLM 003"

Also, this no longer happens after I changed the board type to genericSTM32F103C8, and uploads succeed with no intervention most of the time.

### Problem 3: Upload success but device no longer detected

Was using this:

Changed to:

[env:genericSTM32F103C8]

platform = ststm32

board = bluepill_f103c8

framework = arduino

board_build.mcu = stm32f103c8t6

board_build.core = maple

upload_protocol = dfu

build_flags = -D PIO_FRAMEWORK_ARDUINO_ENABLE_CDC -Os

lib_deps = arpruss/USBComposite for STM32F1@^1.0.9

[env:genericSTM32F103C8]

platform = ststm32

framework = arduino

board = genericSTM32F103C8

board_build.core = maple

upload_protocol = dfu

build_flags = -D PIO_FRAMEWORK_ARDUINO_ENABLE_CDC -Os

lib_deps = arpruss/USBComposite for STM32F1@^1.0.9

- https://github.com/rogerclarkmelbourne/STM32duino-bootloader/issues/122
  - No useful response eventually
- https://community.platformio.org/t/can-not-upload-to-blue-pill-using-dfu/6431/4
- https://medium.com/@jobenas_25464/how-to-work-with-the-stm32-blue-pill-in-platformio-and-not-die-trying-1700250e54e2
  - The author added board variants parameter, but I couldn’t get this to work (compile error). Apparently the result is probably similar by adding the board_build.core=maple. Remember rogerclarkmelbourne bootloader=maple core

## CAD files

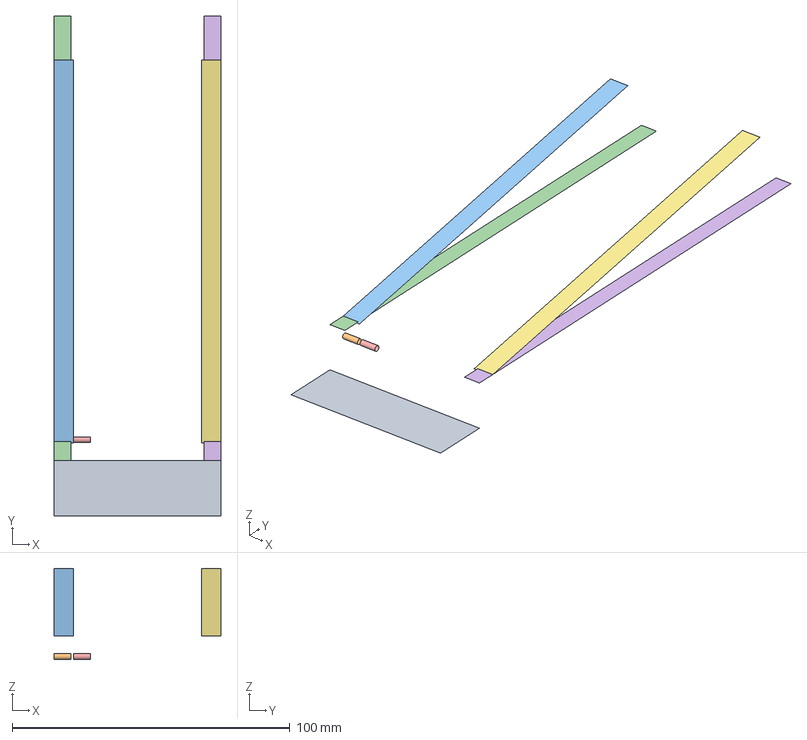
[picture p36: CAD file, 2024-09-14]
cad_models/cc_pedal.FCStd
60.0 x 180.0 x 40.7 mm
_Element
_Element001
_Element007
_Element008
_Element009
_Element010
_Element011

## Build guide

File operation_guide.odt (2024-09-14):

miniPad-α

Finger Drum Pad

Operation Guide

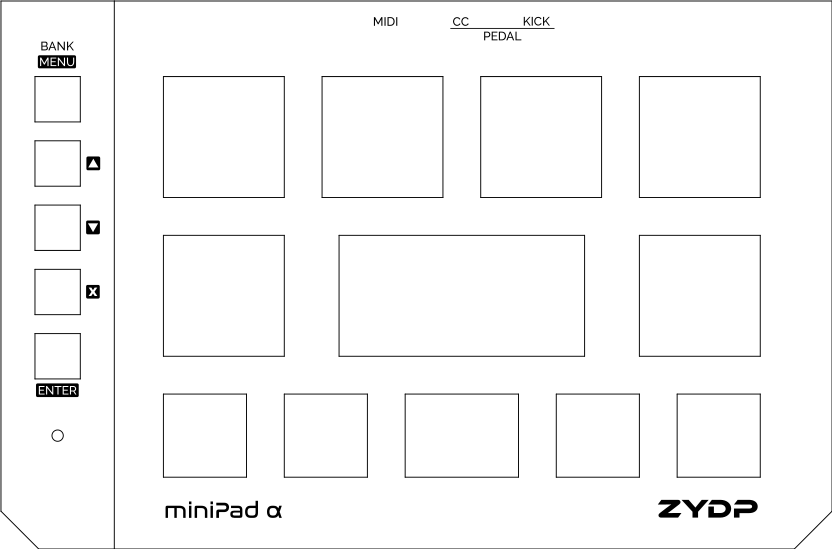
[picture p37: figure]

ZYDP

# Introduction to the miniPad

The ZYDP miniPad is a MIDI finger drum pad which can be used to control external drum synthesizer or sampler. The user can choose between using the USB or TRS MIDI interface for the MIDI output. The miniPad also comes with ports for connecting kick pedal and the hi-hat controller, allowing actual drummers to play the instrument with ease.

## Parts of the miniPad

1. Pads
  - By hitting any of the pads, a MIDI note-on message will be sent through the USB MIDI output (and TRS MIDI depending on settings). The MIDI note assignment of each pads can be customized, refer to Editing the note/controller number assignment for more details. The pads are numbered as illustrated by the diagram below:
2. Buttons
  - The buttons serve different purpose in different interface. The highlighted labels apply for any settings interface, while the non-highlighted apply in the main interface (for details on interface, refer to Interfaces of the miniPad). The details function of each buttons was summarized as follows:
    - Button 1 (BANK/MENU)
      - In the main interface: Cycle between the banks of the pads’ note number assignment. For more details on banks, refer to Banks and slots.
      - In the settings interface: Cycle between different settings. For more details on settings, refer to Settings Interface.
    - Button 2 ()
      - In the main interface: Change to memory slot 1 of the bank.
      - In the settings interface: Increment the value of the selected settings.
      - In the assignment editor interface: Increment the note/controller number of the selected pad/controller by 1.
    - Button 3 ()
      - In the main interface: Change to memory slot 2 of the bank.
      - In the settings interface: Decrement the value of the selected settings.
      - In the assignment editor interface: Decrement the note/controller number of the selected pad/controller by 1.
    - Button 4 ()
      - In the main interface: Change to memory slot 3 of the bank.
      - In the settings interface: Exit settings interface and return to main interface without writing changes to the memory. Any changes will be lost if the drum pad is restarted.
      - In the assignment editor interface: Exit assignment editor interface and return to main interface without writing changes to the memory. Any changes will be lost if the drum pad is restarted.
    - Button 5 (ENTER)
      - In the main interface: Change to memory slot 4 of the bank.
      - In the settings interface: Write any changes to the memory including settings and pad assignment.
3. Status indicator LED
  - The status indicator LED display various state of the drum pad. The general statuses were summarized as follows:
    - Red/Green/Blue/Purple
      - Corresponds to currently selected slot (1-4) in the main interface.
    - White
      - The drum pad is in the settings interface.
    - Blinking slowly in red/green/blue/purple
      - The drum pad is in the assignment editor interface. The colour of the LED represent the slot selected.
    - Blinking quickly for X number of times
      - In the main interface: Currently selected bank is changed to bank X.
      - In the settings interface: Currently selected settings is settings X.
    - Blinking very quickly in white
      - Settings and pad assignment have been successfully written to the memory.
4. Output ports
  - The output ports are for interfacing with external controller/to other devices. The ports and their corresponding function were labelled on the front panel of the drum pad. The functions of each ports were summarized as follows:
    - MIDI output
    - The MIDI output port is for connecting the drum pad to other instrument/drum synthesizer. The standard connection (Type A) as per MIDI specification for TRS MIDI is implemented in this drum pad, that is tip-sink, ring-source, and sleeve-shield. Any suitable MIDI TRS to DIN5 adapter may be used as long as the Type A connections were followed.
    - CC pedal
    - The CC (control change/continuous control) pedal can be connected to this port in order to control the assigned CC number. In the default assignment, the pedal is assigned to CC4 which control the hi-hat opening and closing in most drum sampler. The assignment can be customized on a per-slot basis.
    - Kick pedal
    - The kick pedal (which is essentially a foot controlled pad) can be connected to this port. In the default assignment, the pedal is assigned to MIDI note 36 (bass drum as per General MIDI 2 standard). However, the assignment can be customized on a per-slot basis as well.
5. USB MIDI output
  - This USB output should be connected to a HOST device which can receive MIDI over USB. The USB connection is also used for serial communication (not yet implemented in alpha).

# Quick Start

## Setting Up the miniPad

### Connecting pedals

The miniPad comes with two pedal unit: the kick pedal and the CC pedal. The pedals can be connected connected by using a 3.5mm TRS audio cable. Plug one end of the cable to the pedal unit and the other end to the corresponding port at the back of the miniPad.

Please note that the pedal need to be enabled in the settings before you can use it. The settings for enabling the kick pedal and CC pedal are located at 3rd and 4th index respectively. Refer to Settings Interface for how to change it.

## Connecting the miniPad to External Synthesizer

### Through the TRS MIDI output

The TRS MIDI output can be connected by using a 3.5mm TRS audio cable. Plug one end of the cable to the miniPad MIDI port while the other end to the synthesizer device. You may use TRS to DIN adapter if the synthesizer MIDI input requires a 5-pin DIN connector.

To power the miniPad, connect the USB port on the miniPad to a 5V USB power supply. This may be your phone charger, powerbank, or even just your laptop.

Please note that the TRS MIDI output need to be enabled in the settings before you can use it. The setting for enabling the TRS MIDI output is located at 2nd index. Refer to Settings Interface for how to change it.

### Through the USB MIDI output

The USB MIDI output can be connected by using a micro-USB cable. Plug one end of the cable to the miniPad USB port while the other end to your device (computer/laptop). You can connect the miniPad to your phone or tablet by using an USB OTG adapter, providing that you have compatible drum sampler apps installed.

Then, select the miniPad as your MIDI input device in your sampler software. The exact procedure may differ from one software to another, you may need to refer to the software user manual.

## Playing the miniPad

When the miniPad is powered up, it will enter the main interface by default. You can now play the drum pad by hitting the pad with your finger. A MIDI note-on message will be sent when you hit the pad, and the velocity of the MIDI message sent depends on how hard you hit the pad.

## Changing the MIDI Channel Number

Depending on your synthesizer or sampler, some might requires the MIDI message to be sent over certain channel in order for it to create sound. The miniPad allows you to change the MIDI channel number in the settings by accessing the first index of the settings. The MIDI channel numbers that you can set are from 1 to 16, with an additional option to send to all channels. By default, the channel number is set to 1. Refer to Settings Interface for how to change it.

## Changing the Velocity Curve of the Pads

The velocity curve of the pads refer to how sensitive the pads respond to finger hits. A soft velocity curve means that you can hit the pads lightly while still producing loud notes, while a hard velocity curve means that you need to hit the pads harder to produce loud notes. In general, hard velocity curve allows for wider dynamic range, although this is partly dependent on the synthesizer that you are using. By default, the velocity curve is set to medium.

To change the velocity curve, the settings is located at the 5th and 6th index for pads on the miniPad and the kick pedal respectively. For more details on the velocity curve settings, refer to Settings Interface.

## Other Common Operations of the miniPad

For the other common operations that you can do on the miniPad, refer to the list below:

1. Changing between banks and slots
2. Customizing pads and pedal assignment
3. Writing settings and assignments to the memory

# Interfaces of the miniPad

## Main Interface

The main interface is where you will be spending most of the time using the drum pad in. You will be able to change between different banks and memory slots, where you can define different note/controller number assignment to the pads and the controller.

### Banks and slots

The miniPad has 4 banks, each bank containing 4 slots, totalling up to 16 different sets of pads assignment that can be customized and saved.

### Changing between slots

By default when the drum pad is turned on, the first memory slot is selected (red). To change between slots, buttons 2-5 can be pressed one time to change to the corresponding memory slot. The status indicator LED will change its colour to match the colour of the slot button pressed.

Button | Memory Slot | Colour of Status Indicator LED
2 () | 1 | Red
3 () | 2 | Green
4 () | 3 | Blue
5 (ENTER) | 4 | Purple

### Changing between banks

By default when the drum pad is turned on, the first bank is selected. Press the BANK/MENU button to cycle between banks. The status indicator LED will blink quickly for a number of times equal to the index of the selected bank when the BANK/MENU button is pressed.

## Settings Interface

The settings interface is where you can change various behaviour of the drum pad, such as MIDI settings, external devices settings, and pads settings.

### Entering the settings interface

To enter the settings interface, ensure the drum pad is at the main interface, then long press the BANK/MENU button. The status indicator will turn to white colour, indicating that you are currently in the settings interface.

### Changing between settings

To cycle between the settings, press the BANK/MENU button. The status indicator LED will blink quickly for a number of times equal to the index of the selected settings.

### Changing the value of the selected settings

To change the value of the selected settings, press button to increment the value and button to decrement the value. If the last value is reached and is pressed, the value will cycle back to the first value. If the first value is reached and is pressed, the value will cycle back to the last value.

### List of settings

No. | Settings | Description | Value Range | Default Value
1 | MIDI channel | Set the MIDI channel number where the MIDI messages will be sent to. | 1-16, all channels | 1
2 | Toggle TRS MIDI | Enable/disable MIDI over TRS. | Enabled, disabled | Enabled
3 | Toggle kick pedal | Enable/disable kick pedal. | Enabled, disabled | Enabled
4 | Toggle CC pedal | Enable/disable CC pedal. | Enabled, disabled | Disabled
5 | Pads velocity curve | Change the sensitivity of the pads on the drum pad. | Soft, medium, hard | Medium
6 | Kick pedal velocity curve | Change the sensitivity of the kick pedal. | Soft, medium, hard | Medium

### Writing changes to the memory

To write any changes in settings (including pad assignment) to the memory, press the ENTER button while you are in the settings interface. The status indicator LED will blink very quickly, indicating that the changes had been saved to the memory successfully.

Caution: Flash memory have a limited write cycle. Avoid unnecessary writes to the memory to prolong the lifetime of the memory.

### Exiting the settings interface

To exit the settings interface, press the button. The drum pad will return to the main interface. Note that any changes in settings will not be automatically saved when pressing this button.

## Assignment Editing Interface

The assignment editing interface is where you change what MIDI note will be triggered when the pads are triggered. The controller number mapped to the CC pedal is changed in this interface as well.

### Entering the assignment editing interface

To enter the assignment editing interface, first select the bank and slot you want to edit (refer to Banks and slots for more details). Then double click the BANK/MENU button. The status indicator LED will start blinking slowly, indicating that you are in the assignment editing interface.

### Editing the note/controller number assignment

After entering the assignment editing interface, hit the pad that you want to edit the note number assignment to select the pad for editing. Similarly for pedals, press the CC controller or the kick pedal to select either of them for editing.

To increment the note/controller number, press the button. To decrement the note/controller number, press the button. To increment or decrement the note number by one octave, long press the or buttons respectively. You can hit the pad/press the pedal while editing the assignment to determine what changes have been made.

### Exiting the assignment editing interface

Press the button to exit the assignment editing interface. The drum pad will return to the main interface. Note that any changes in note/controller number assignment will not be automatically saved when pressing this button.

### Writing changes to the memory

Writing the note/controller number assignment to the memory uses the same steps as writing settings to the memory. Refer to Writing changes to the memory for more details.

# Specifications

Product Name | | miniPad-α
Size | Dimension (W×D×H) | 220×145×35 mm
| Weight | Did not measure
Pads | Drum Pads | 12
| Assignable Note Number | Yes
Other Interfaces | LED Indicator | RGB status indicator
Registration Memory | User | 4 Slots × 4 Banks
Connectivity | USB to Host | Micro B
| TRS MIDI Out | 3.5mm TRS Tip – Sink Ring – Source Sleeve – Shield
| Kick Pedal | 3.5mm TRS
| CC Pedal | 3.5mm TRS
Power Supply | Power Specification | 5V USB power adaptor
| Current Consumption | Did not measure
| Power Consumption | Did not measure

# Appendix

## Default Pads Mapping

By default the first bank is predefined, where the defined note number can be referred below.

Pad Number | Slot 1 | Slot 2 | Slot 3 | Slot 4
1 | 43 (High Floor Tom) | 43 | 46 | 46
2 | 41 (Low Floor Tom) | 41 | 37 | 37
3 | 36 (Bass Drum 1) | 37 (Side Stick) | 38 | 38
4 | 41 | 41 | 41 | 41
5 | 43 | 43 | 43 | 43
6 | 47 (Low-Mid Tom) | 47 | 42 | 42
7 | 38 (Acoustic Snare) | 38 | 50 (High Tom) | 50
8 | 47 | 47 | 45 (Low Tom) | 45
9 | 49 (Crash Cymbal 1) | 49 | 49 | 49
10 | 46 (Open Hi-hat) | 46 | 54 (Tambourine) | 55 (Splash Cymbal)
11 | 42 (Closed Hi-hat) | 42 | 57 (Crash Cymbal 2) | 57
12 | 51 (Ride Cymbal 1) | 51 | 51 | 51
Kick pedal | 36 | 36 | 36 | 36
CC pedal | CC4 | CC4 | CC4 | CC4

## Using With FL Studio FPC Plugin

1. Ensure that low-latency audio driver is selected and used. Go to Options → Audio settings, in the Device drop-down menu, select ASIO4ALL v2. Select buffer length of less than 256 samples.

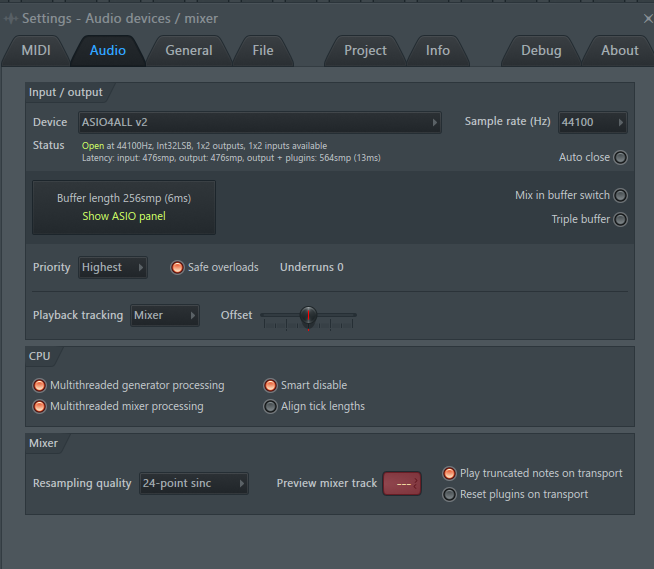
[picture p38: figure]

2. Go to Options → MIDI settings and under the “Input” list select the miniPad and click “Enable”.
3. Open the FPC plugin by going to Add → FPC.
4. Hit any of the pads to confirm that you have successfully connected the drum pad.

miniPad-α | Operation Guide ZYDP

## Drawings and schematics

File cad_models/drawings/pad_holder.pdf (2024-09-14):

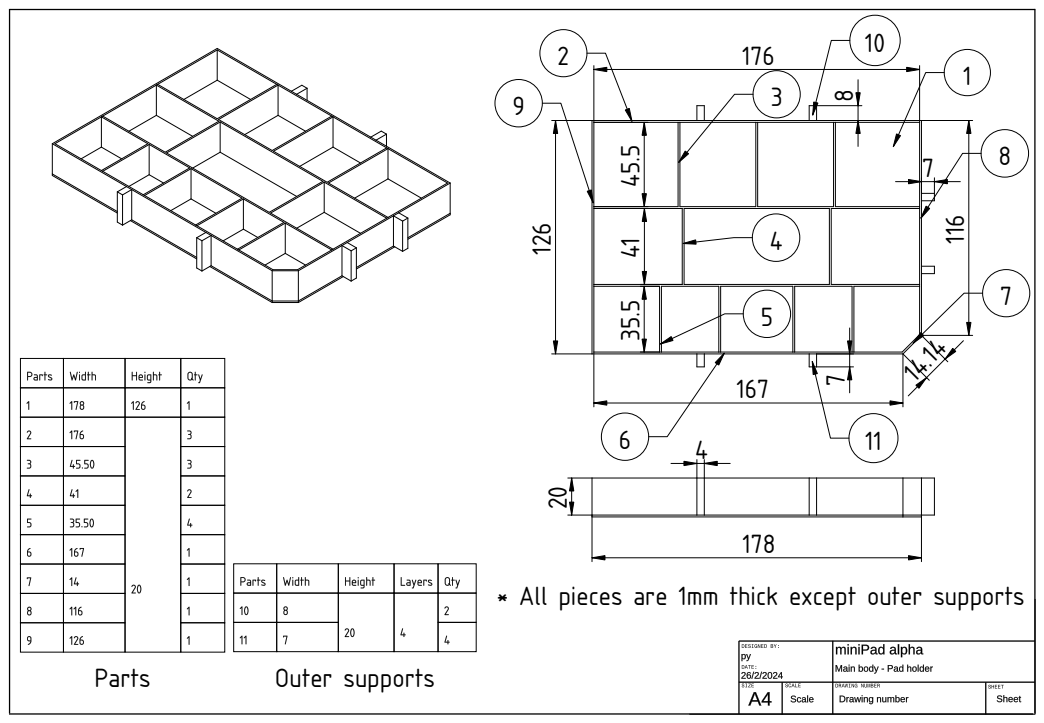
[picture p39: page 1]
Parts; Outer supports

* All pieces are 1mm thick except outer supports

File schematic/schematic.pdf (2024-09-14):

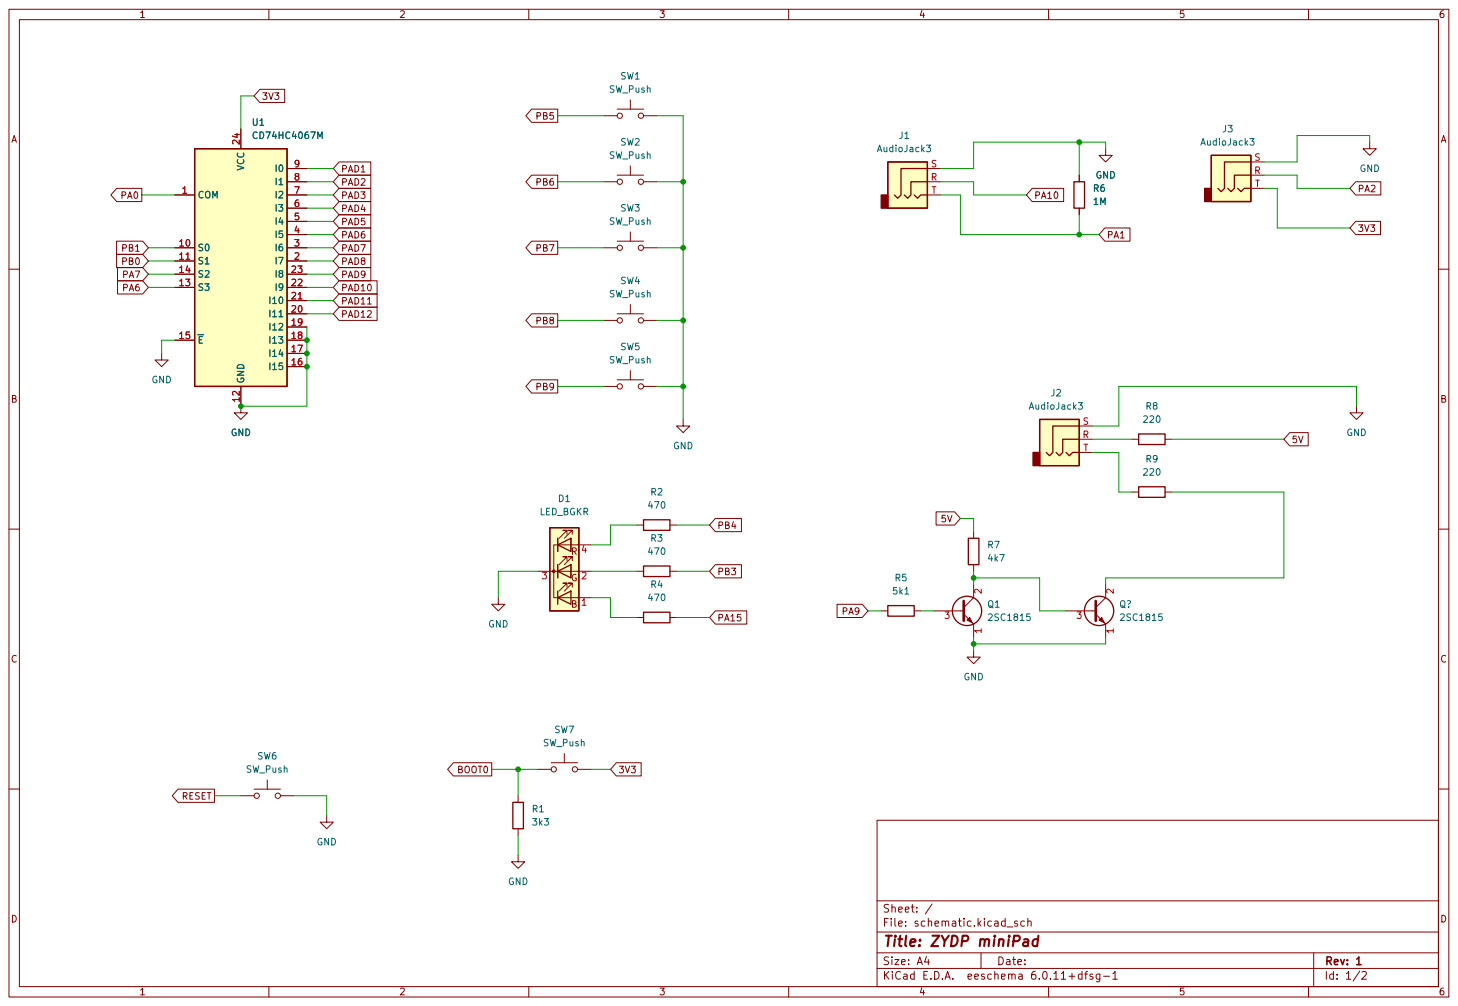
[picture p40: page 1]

Id: 1/2 Title: ZYDP miniPad

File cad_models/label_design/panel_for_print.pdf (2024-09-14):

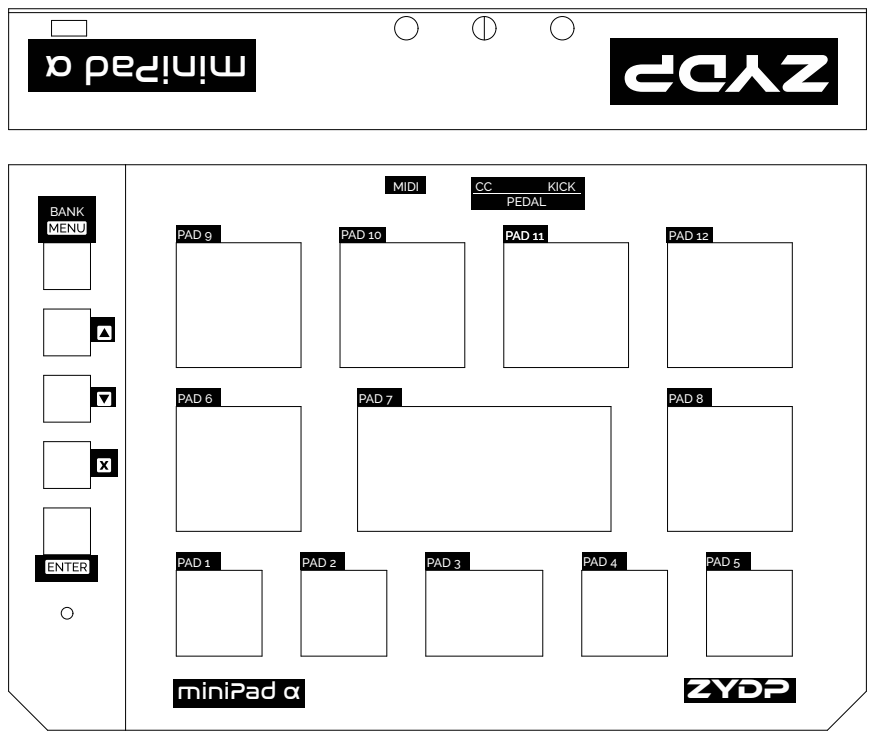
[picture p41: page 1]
MIDI; KICK; PEDAL; miniPad α; ZYDP; PAD 1; PAD 2; PAD 3; PAD 4; PAD 5; PAD 6; PAD 7; PAD 8; PAD 9; PAD 10; PAD 11; PAD 12; BANK

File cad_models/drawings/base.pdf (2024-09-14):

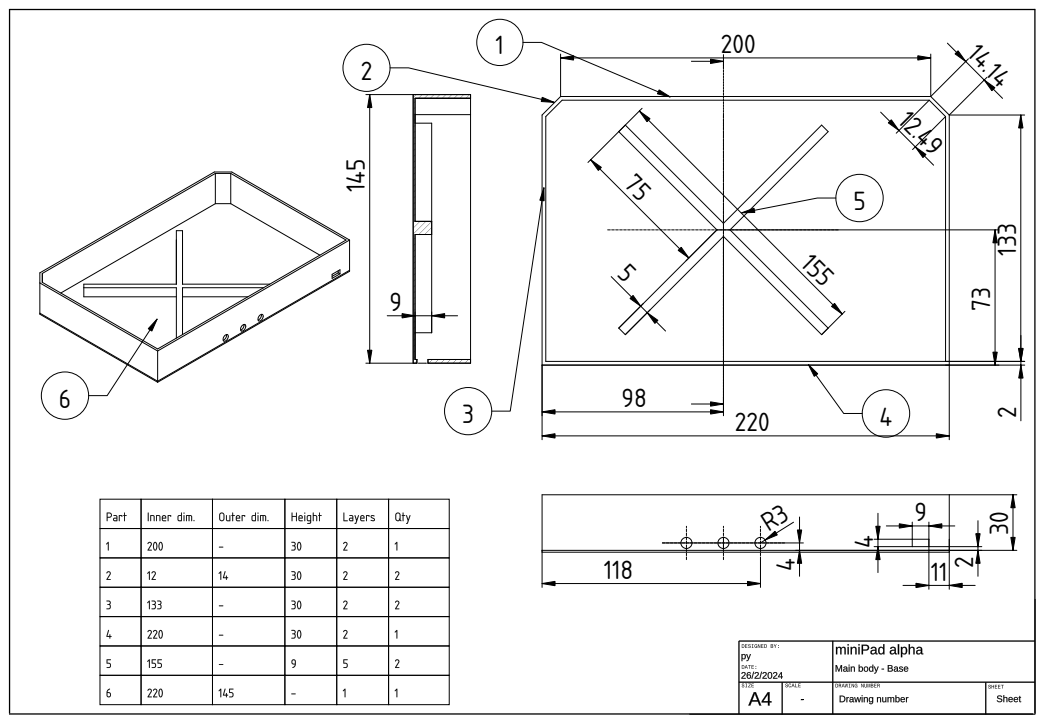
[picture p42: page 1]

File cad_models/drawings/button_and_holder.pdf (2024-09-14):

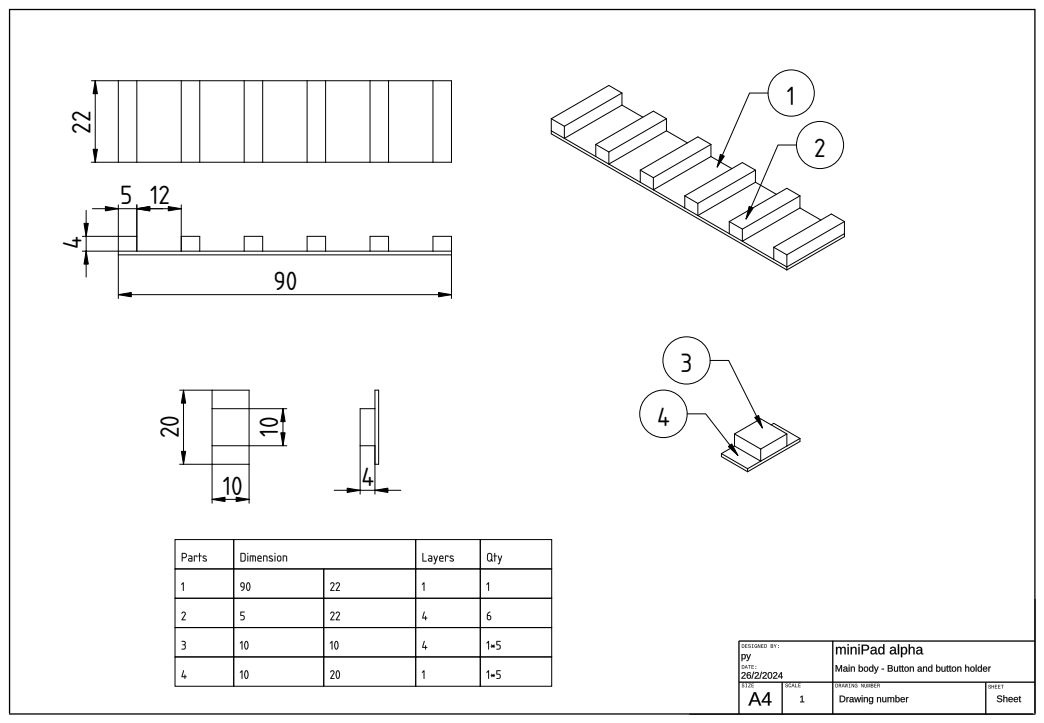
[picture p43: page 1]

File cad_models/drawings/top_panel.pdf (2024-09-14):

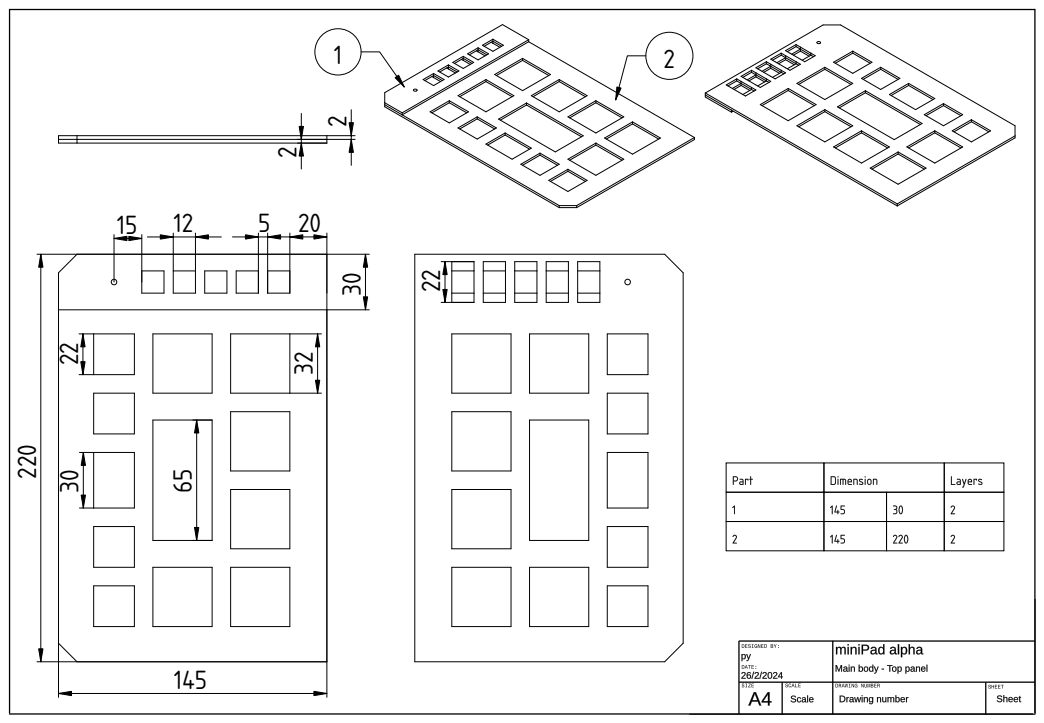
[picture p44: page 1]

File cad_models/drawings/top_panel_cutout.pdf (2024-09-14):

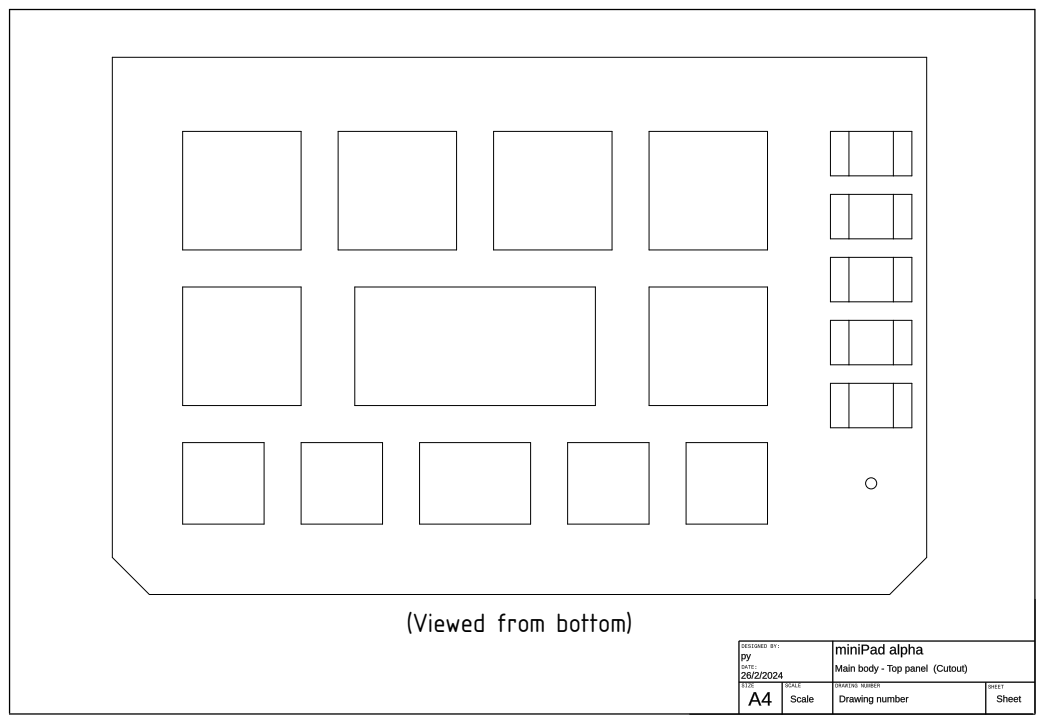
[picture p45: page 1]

(Viewed from bottom)
